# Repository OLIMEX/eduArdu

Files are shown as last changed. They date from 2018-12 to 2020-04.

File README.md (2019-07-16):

# eduArdu
Open Source Hardware Educational board based on Arduino Leonardo

Product page: https://www.olimex.com/Products/Duino/AVR/eduArdu/open-source-hardware

Introduction video: https://youtu.be/3kFrveMF56s

# Getting started

## Arduino IDE

* [Download and install Arduino IDE](https://www.arduino.cc/en/Main/Software)
* Open Arduino IDE
* Click **Sketch > Include Library > Add .ZIP library...** and add all libraries provided with this repository
* Open a sketch, compile and upload it to Olimex eduArdu

## Licensee
* Hardware is released under Apache 2.0 Licensee
* Software is released under GPL3 Licensee
* Documentation is released under CC BY-SA 3.0

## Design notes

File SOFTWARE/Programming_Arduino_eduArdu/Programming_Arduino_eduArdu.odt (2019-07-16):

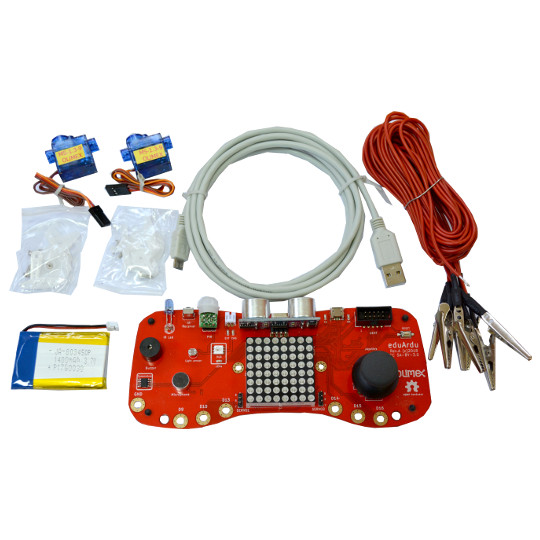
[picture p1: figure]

Програмиране с Arduino и eduArdu

July 2019

# 1. Инсталиране на Arduino IDE

1.1 Използвайте линка за сваляне на Arduino IDE в зависимост от операционната система :

https://www.arduino.cc/en/Main/Software

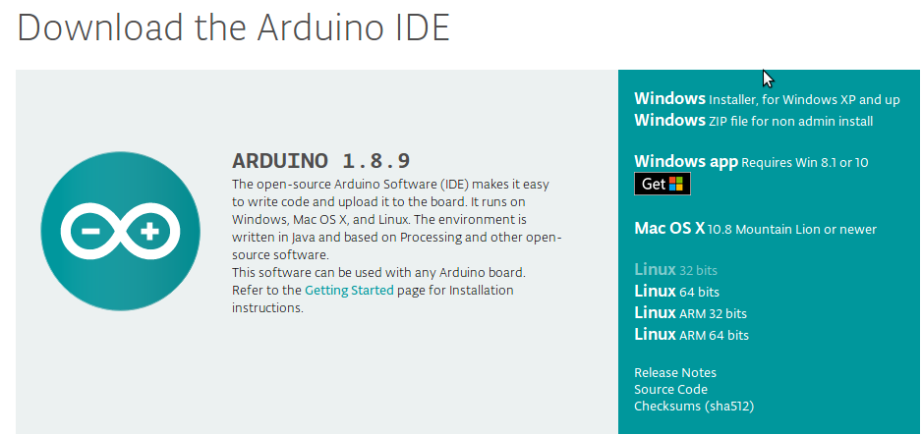
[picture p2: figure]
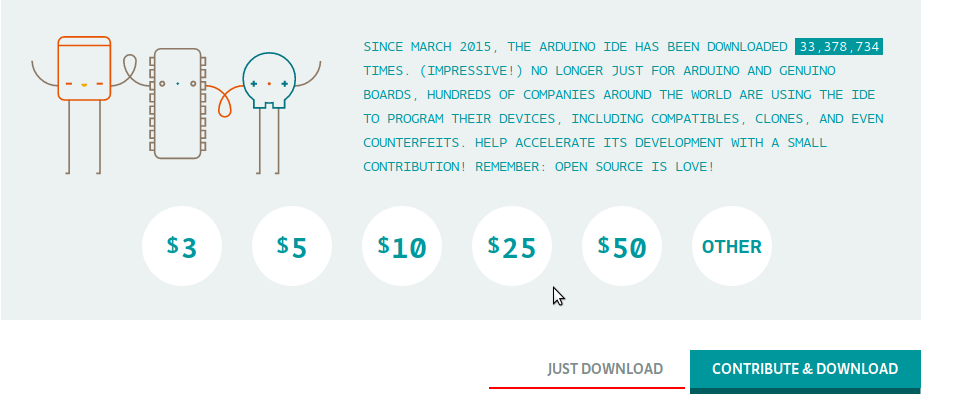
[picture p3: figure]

2.1 Инсталирайте Arduino IDE

3.1 Използвайте линка за да свалите всички примери и библиотеки необходими за eduArdu чрез натискането на подчертания бутон :

https://github.com/OLIMEX/eduArdu

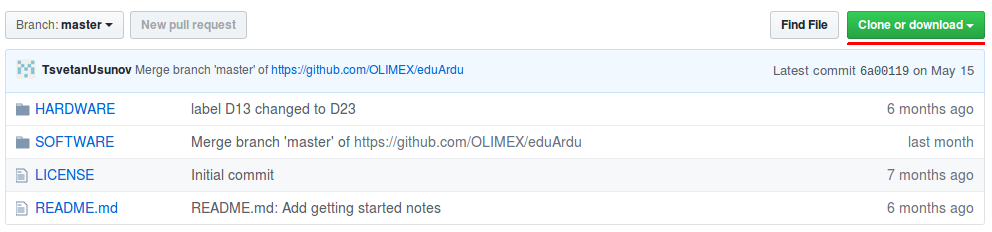
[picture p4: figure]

4.1 Стартирайте Arduino IDE. Влезте в Sketch-include Library-Add .ZIP Library

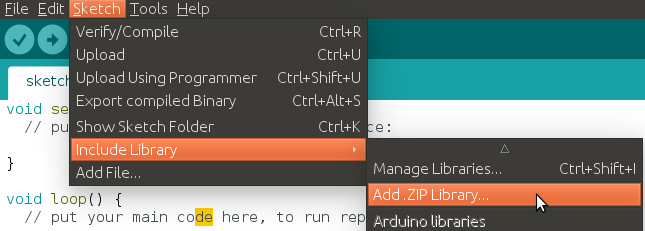
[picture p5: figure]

5.1 Изберете папката в която сте запазили сваленото от точка ( 3. ) и започнете едно след друго да добавяте библиотеките, като следвате стъпки 4 и 5 . Файловете, който трябва да добавите ще се намират под Files а папката в която сте запализи файла от точка 3 ще се намира под Folders.

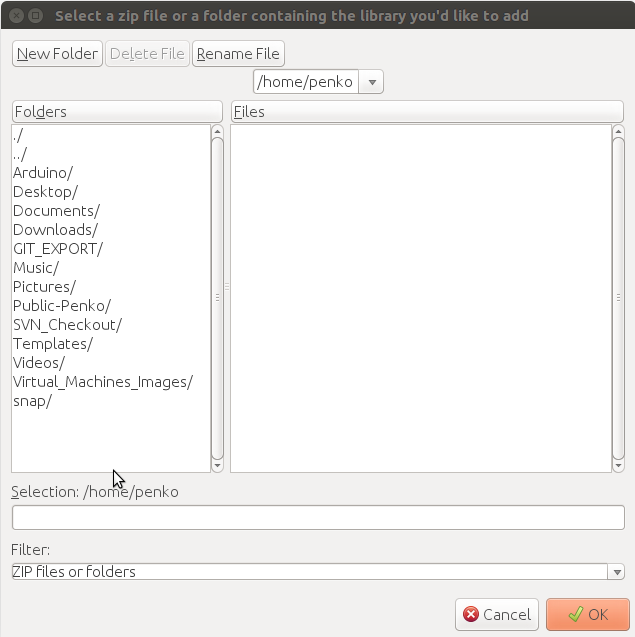
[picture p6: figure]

За eduArdu :

Платката EduArdu е предназначена за обучение. Тя е снабдена с множество сензори като например:

-осветление

-инфрачервен диод

-инфрачервен приемник

-сензор за движение

-сензор за температура

Платката разполага още и с:

-LED матрица

-микрофон

-трицветен светодиод

-два Servo входа

-джойстик

-UEXT вход

-Buzzer

# 2. Инсталиране на Olimex board support

Влизате в file-preference.

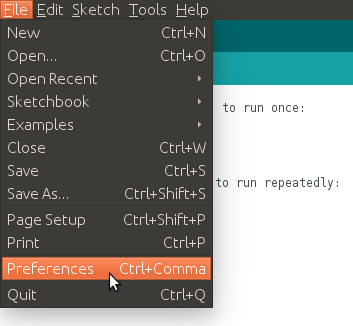
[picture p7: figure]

Копирате линка:

h (https://raw.githubusercontent.com/OLIMEX/Arduino_configurations/master/AVR/package_olimex_avr_index.json)ttps://raw.githubusercontent.com/OLIMEX/Arduino_configurations/master/AVR/package_olimex_avr_index.json

След това го поставяте в Additional board manager URLs:

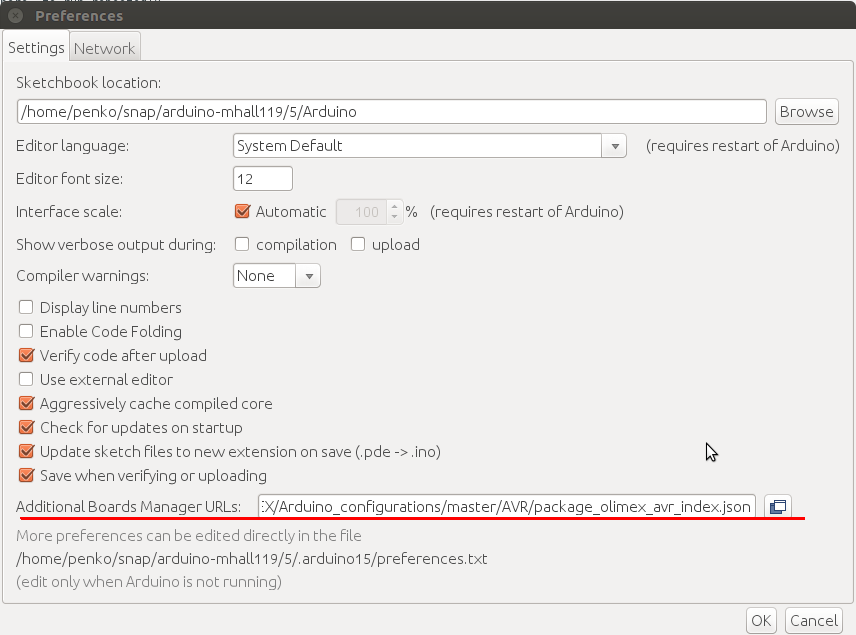
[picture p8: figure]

Влезте в tools-board-boards manager : и инсталирайте Olimex AVR boards.

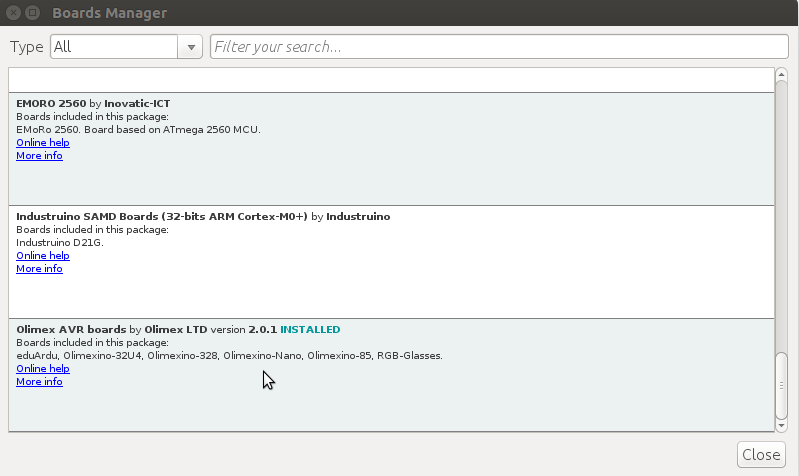
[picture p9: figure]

# 3. Как да конфигурираме Arduino IDE

Първо: Свържете платката с USB към компютър. Втора стъпка:конфигурирайте платката като за целта трябва да влезнете в Tools-Board и изберете eduArdu. След това Port и изберете вашата платка.

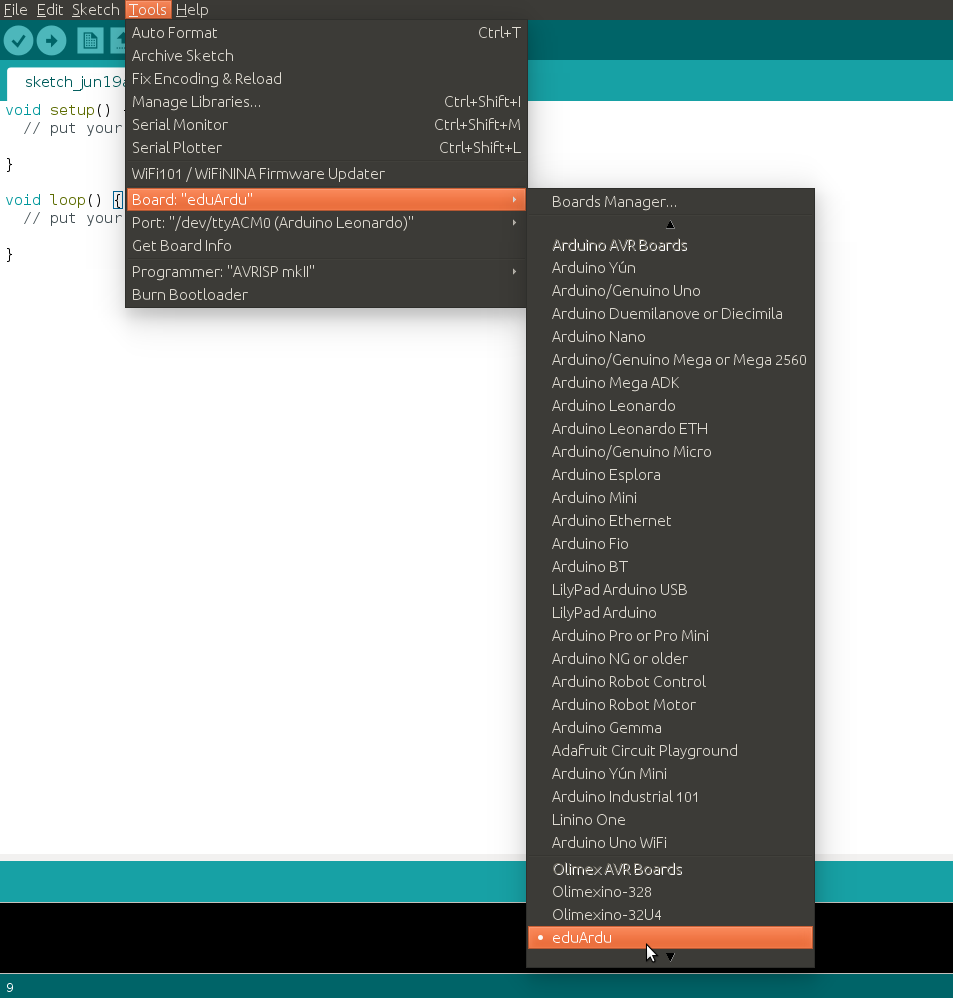
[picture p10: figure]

# 4. LED Matrix

#include <string.h>

#include "LED_Matrix.h" // Използваме LED_Matrix.h за да имаме достъп до SlideRight() // и SlideLeft().

#include "font.h" // Чрез font.h инициализираме азбуката и всички знаци.

#include "Joystick.h" // Инициализира джойстика.

#define JOYSTICK_X A0 // Където срещне OYSTICK_X го заменя с аналогов вход A0.

#define JOYSTICK_Y A1 // Където срещне OYSTICK_Y го заменя с аналогов вход A1.

#define JOYSTICK_BUTTON 31 // Където срещне JOYSTICK_BUTTON го заменя с 31

#define SPEED 110 // Където срещне SPEED го заменя с 110

#define LED_LATCH 11 // Инициализираме LED матрицата.

#define LED_DATA 16

#define LED_CLOCK 15

LED_Matrix Matrix(LED_LATCH,LED_DATA,LED_CLOCK); // Задаваме стойност на функция Matrix // която приема като параметри LED // Matrix pin.

Joystick Joy(JOYSTICK_X, JOYSTICK_Y); // Използваме функцията за да взимаме // стойностите на Х(лява/дясна граница) и на // Y(горна/долна граница) на джойстика.

unsigned char Text[STRING_MAX_CHAR] = "Olimex eduArdu LED matrix example!";

/*

Използва се за изписването на текста върху LED matrix.Пример ако искаме да изпишем

“Hello Olimex” трябва да го променим така :

unsigned char Text[STRING_MAX_CHAR] = "Hello Olimex";

*/

char Terminal_Output[256]; // Използва се за изписване на резултатът в конзолата // като дължината на символите зависи от цифрата // която е в скобите “[ ]”.

void setup()

{

Serial.begin (115200); // Използва се за инициализиране.Т.е скоростта на // трансфера на данните.

Matrix.DisplayText (Text, 0); // Използва се за инициализиране на текста като // втория параметър е за да може текста да започне
} // отначало.

static unsigned long Time=0, PrevTime=0; // Задаваме стойности за променливи Time,PrevTim.

Time = millis(); // Записваме в Time, изтеклото време в милисекунди от // пускането на платката.

if (Time-PrevTime > 110) // Изважда от Time променливата PrevTime и провер
{ // дали е по малко от 110.

PrevTime = Time; // PrevTime взема стойността на Time.

if (Joy.X () < 20) // Проверява дали джойстика е натиснат наляво.

Matrix.SlideLeft (1); // Ако е натиснат наляво. Функцията премества текста // наляво.

if (Joy.X () > 80) // Проверява дали джойстика е натиснат надясно.

Matrix.SlideRight (1); // Ако е натиснат надясно.Функцията премества текста // надясно.

if (Joy.Y () < 20) // Проверява дали джойстика е натиснат надолу. Ако е // натиснат преминава на другия ред и извиква // функцията която намалява светлината.
Matrix.ChangeBrightness (-10);

if (Joy.Y () > 80) // Проверява дали джойстика е натиснат нагоре. Ако е // натиснат преминава на другия ред и извиква // функцията която увеличава светлината.

Matrix.ChangeBrightness (10);

Serial.println ("--------------------------------"); // Изписва на конзолава намиращите

// се символи между кавичките в // скобите.

sprintf (Terminal_Output, "Joystick: X = %d%%; Y = %d%%; Button: %d", (int)Joy.X(), (int)Joy.Y(), Joy.But()); // Взима стойностите X,Y,Button и ги записва в // Terminal_Output

Serial.println (Terminal_Output); //Изписва съдържанието на Terminal_Output.

}

Matrix.UpdateText (); //Актуализира матрицата.

}

# 5. Масиви

Това са последователни клетки от паметта в който можем да запазваме различни данни от различен тип. Пример за това е в проекта Led Matrix,използването на :

unsigned char Text[STRING_MAX_CHAR] = "Olimex eduArdu LED matrix example!";

char Terminal_Output[256];

При тези масиви искаме да запишем думи. Пример ако искаме да сменим текста който се изписва на матрицата ще променим текста в кавичките :

unsigned char Text[STRING_MAX_CHAR] = "Hello Olimex";

така текста на матрицата ще се промени.

# 6. Функции и Проверки

Тук ще разгледаме някой от функциите и проверките в примера за Led Matrix.

## 6.1 Функции

void setup()

{

Serial.begin (115200);

Matrix.DisplayText (Text, 0);

}

За пример можем да вземем Void Setup() тази функция не връща като резултат нищо.Използва се за инициализиране на входове/изходи. В тялото(т.е. намиращото се в { } ) на тази функция имаме Serial.begin (115200); което инициализира скоростта на трансфер на данните.

Функцията Matrix.DisplayText (Text, 0); изписва на екрана записания текст в масива Text и откъде да започне текста като ако применим втория параметър (Text, 0) да не е 0 ще видим че текста се измества.

## 6.2 Проверки

Нека разгледаме

if (Time-PrevTime > SPEED)

{

PrevTime = Time;

if (Joy.X () < 20)

Matrix.SlideLeft (1);

if (Joy.X () > 80)

Matrix.SlideRight (1);

if (Joy.Y () < 20)

Matrix.ChangeBrightness (-10);

if (Joy.Y () > 80)

Matrix.ChangeBrightness (10);

}

Тук имаме проверки “ if () ” при нея можем да сложим условие в ( ), проверяваме,ако условието е изпълнено(вярно е) програмата преминава на следващия ред и го изпълнява.При първият if (Time-PrevTime > SPEED) проверяваме Time-PrevTime дали е по-голямо от SPEED където SPEED e зададено като статична стойност чрез #define SPEED 110 намиращо се в началото на програмата.Пример за променянето на SPEED e :

#define SPEED 40

така след промяната на текста чрез натискане на джойстика,той ще се движи по-бързо.

Когато програмата навлезе в тялото на функцията :

{

PrevTime = Time;

if (Joy.X () < 20)

Matrix.SlideLeft (1);

if (Joy.X () > 80)

Matrix.SlideRight (1);

if (Joy.Y () < 20)

Matrix.ChangeBrightness (-10);

if (Joy.Y () > 80)

Matrix.ChangeBrightness (10);

}

Тук отново имаме проверки от тип if ( ) при тях обаче проверяваме дали сме натиснали джойстика if (Joy.X () < 20) наляво ако условието в скобите ( ) е изпълнено, т.е. джойстика е натиснат,наляво програмата изпълнява Matrix.SlideLeft (1); .При изпълнението на тази функция можем да променим стойността с която текста преминава през матрицата :

Matrix.SlideLeft (3) стойността може да е произволна.

Същото при Matrix.ChangeBrightness (-10); може да променяме колко да се увеличава осветителността.

# 7. Цикли

Тук ще се запознаем с основните цикли. For () , While() ,do While.

## 7.1 Цикъл For ( )

for(int i=0; i<50; i++)

{

//тяло на цикъла

}

В този пример операндите, който приема цикъла са нулиране на применливата “i” int i=0,

приверка дали “i” е по-малко от 50 и увеличаване на “i” с едно. Програмата преминава през цикъла по следния начин :

1. Нулирането на “i” (int i=0)

2.Проверка дали “i” е по-малко от 50

3.Навлизане и изпълнение на тялото на цикъла

4.Увеличаване на “i” с едно

Пример за такъв цикъл ще дадем от програмата с използване на микрофона:

for(int i=0; i<50; i++)

{

int Sample;

Sample = analogRead(MICROPHONE);

if (Sample > Max)

Max = Sample;

if (Sample < Min)

Min = Sample;

if((Max-Min) > THRESHOLD)

{

digitalWrite (LED, !digitalRead(LED));

delay(100);

break;

}

}

За тялото на функцията и проверките в него, може да прочетете в глава 6.

## 7.2 Цикъл While ( )

Тук цикъла има само един параметър и това е условието :

While (“условие”)

{

//тяло на цикъла

}

При този цикъл докато условието е вярно ще се повтаря кода в тялото.

## 7.3 Цикъл do While ( )

Тук цикъла има пак един параметър и това е условието но тук тялото се изпълнява и след това се прави проверката :

do

{

//тяло на цикъла

}While (“условие”)

!! Внимание цикъла може да се изпълни поне един път.

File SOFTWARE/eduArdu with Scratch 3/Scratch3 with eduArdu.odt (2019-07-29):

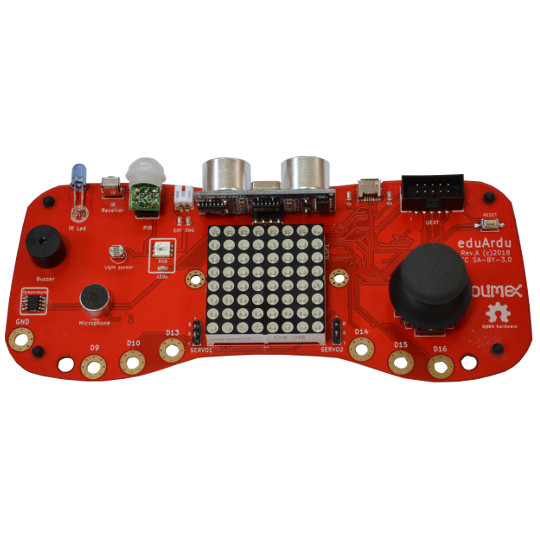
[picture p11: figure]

First steps with

Scratch 3 and eduArdu

Rev.1 July 2019

olimex.com

# Step 1 prepare eduArdu

What you need is eduArdu (https://www.olimex.com/Products/Duino/AVR/eduArdu/open-source-hardware) or (https://www.olimex.com/Products/Duino/AVR/eduArdu/open-source-hardware)eduArdu-QS (https://www.olimex.com/Products/Duino/AVR/eduArdu/open-source-hardware) Open Source Hardware board from Olimex.

Then you need to program it with example #20 from GitHub (https://github.com/OLIMEX/eduArdu/tree/master/SOFTWARE)

20_eduArdu_Makey-Makey

The code program eduArdu when sense touch to D9-D16 to send these keys:

D9 - „a“

D10 - „s“

D13 - „d“

D14 - „f“

D15 - „g“

D16 - „w“

Joystick Up – Key-Up

Joystick Down – Key-Down

Joystick Left – Key-Left

Joystick Right– Key-Right

Joystick Button – Space

Note that you can re-define any of these in the code if you need!

# Step 2 configure Scratch3

Go to Scratch 3 web site:

https://scratch.mit.edu/

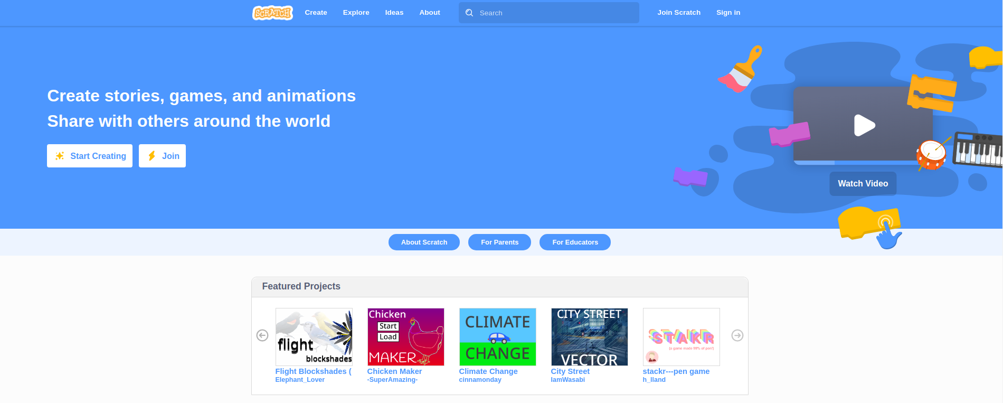
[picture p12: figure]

Click on „Start Creating“, you will see project page:

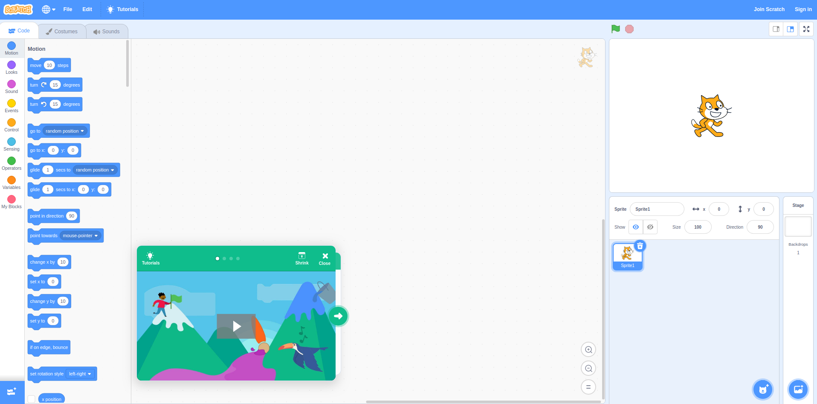
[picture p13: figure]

Click on Down Left corner „Add-Extension“ icon:

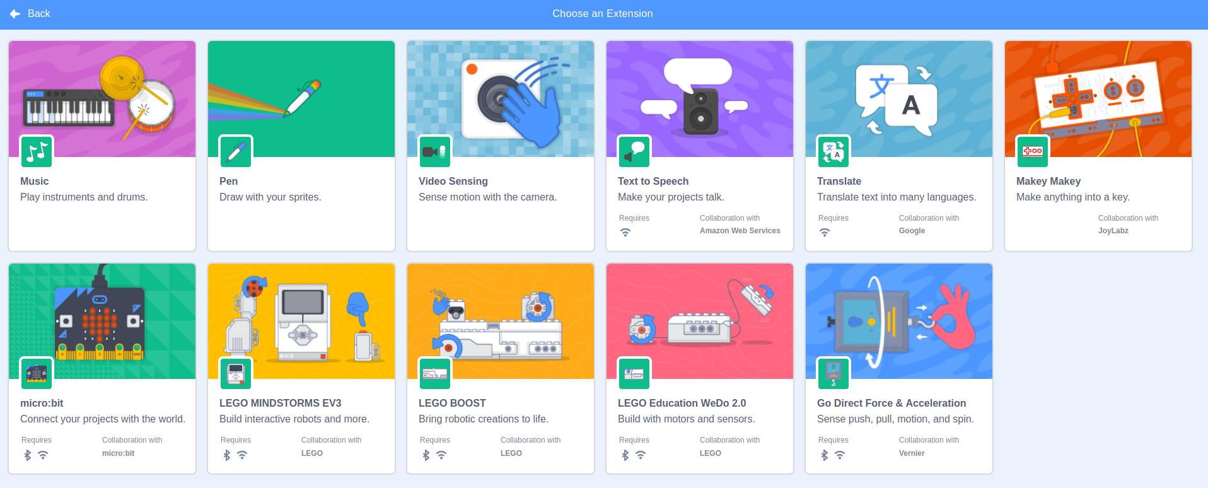
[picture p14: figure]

Select Makey Makey , when yo ugo bsck you will see new MakeyMakey blocks:

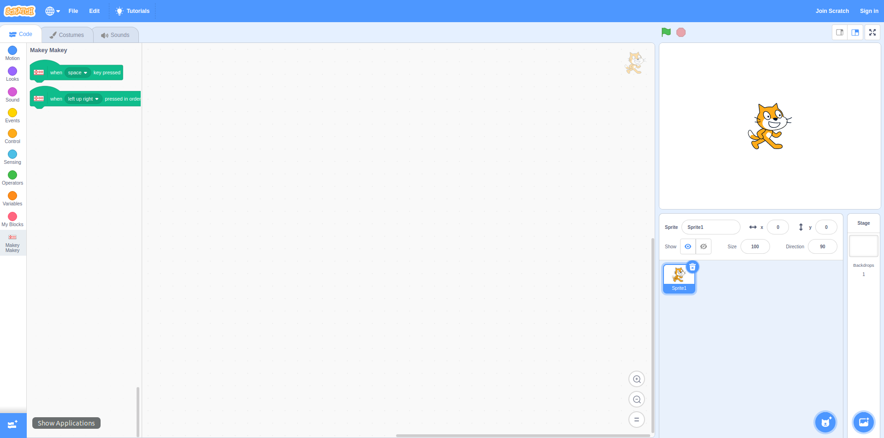
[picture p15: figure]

# Step 3 write your own program

Now you can make your program using MakeyMakey blocks.

The program below does this: when D9 is touched the Cat will say „Hello“, when D10 is touched the Cat say „Hmm“, when D13 is tpoouched Meow sound is payed.

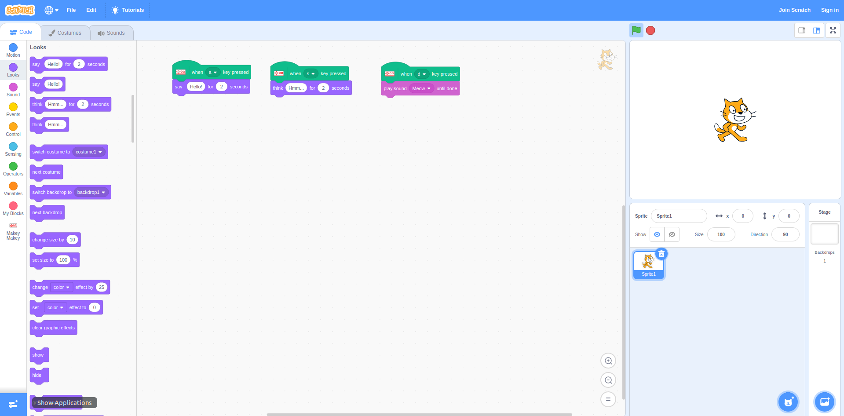
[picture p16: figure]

Here you can see this in action: https://youtu.be/GwdAzChfQ9Y

Have fun!!

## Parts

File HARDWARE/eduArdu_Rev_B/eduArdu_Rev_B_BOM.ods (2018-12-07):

Designation | Quantity | Designator | Package
СВЕТОДИОД МАТРИЦА 8x8 GYXM-1588ASRD | 1 | U9 | GYX1588AB
SMD КОНД 0805 47 UF 6.3V 20% | 7 | C11, C12, C17, C18, C24, C25, C26 | C_0805_5MIL_DWS
SMD КОНД 0603 1 UF 10V X5R | 6 | C1,C6,C13,C16,C22,C23 | C_0603_5MIL_DWS
SMD РЕЗ 0402 10 M 5% | 6 | R26, R27, R28, R29, R30, R31 | R_0402_5MIL_DWS
СЪЕДИНИТЕЛ DW02R | 1 | BAT_CON1 | LIPO_BAT-CON2DW02R
PIR-SB312 | 1 | PIR1 | HN1x3
ИС VS1838B | 1 | U3 | RPM7236-H8-V
SMD СЪЕДИНИТЕЛ B-V-10-LF (GBH254SMT-10) | 1 | UEXT1 | UEXTM-SMD
SMD ИС LM358DR SOIC8 | 1 | U10 | SO-8
SMD РЕЗ 0402 10 K 5% | 10 | R2, R3, R8, R10, R11, R18, R20, R21, R22, R25 | R_0402_5MIL_DWS
SMD РЕЗ 0402 20 K 5% | 1 | R24 | R_0402_5MIL_DWS
SMD РЕЗ 0402 100 OHM 1% | 3 | R14,R17,R19 | R_0402_5MIL_DWS
SMD РЕЗ 0402 100 K 5% | 1 | R16 | R_0402_5MIL_DWS
SMD РЕЗ 0402 1 K 5% | 1 | R15 | R_0402_5MIL_DWS
SNS-LDR5MM | 1 | R7 | R_PHOTO
SMD СЪЕДИНИТЕЛ MISB-SWMM-5B-LF | 1 | USB1 | USB-MICRO_MISB-SWMM-5B_LF
SMD ИС AP1231-3.3V (SOT23-5) | 1 | VR1 | SOT-23-5
SMD ИС TCN75AVOA713 | 1 | U4 | SO-8
BL4054B-42TPRN(SOT23-5) | 1 | U1 | SOT-23-5
SMD РЕЗ 0402 2 K 5% | 4 | R1,R4,R9,R23 | R_0402_5MIL_DWS
SMD РЕЗ 1206 6.8 OHM 5% | 1 | R13 | R_1206_5MIL_DWS
SMD РЕЗ 0402 22 OHM 5% | 3 | R5,R6,R12 | R_0402_5MIL_DWS
SMD СВЕТОДИОД 0603 ЖЪЛТ 300 mCd | 3 | LED1,LED4,LED6 | LED_0603_KA
WS2812S | 1 | LED5 | WS2812_NO_SILK
SMD СВЕТОДИОД 0603 ЗЕЛЕН 300 mCd | 2 | LED2,LED3 | LED_0603_KA
IRML6402 | 1 | FET1 | SOT23
SMD ДИОД 1N5819 (SS14) SMA | 1 | D1 | SMA-KA
SMD КОНД 0402 47 PF C0G 5% 50VDC | 1 | C21 | C_0402_5MIL_DWS
SMD КОНД 0402 100 NF 10% 10VDC | 8 | C5, C8, C9, C10, C14, C15, C19, C20 | C_0402_5MIL_DWS
SMD КОНД 0603 2.2 UF X5R 6.3VDC 10% | 2 | C2,C7 | C_0603_5MIL_DWS
SMD КОНД 0402 20 PF NP0 50VDC | 2 | C3,C4 | C_0402_5MIL_DWS
RA1206_(4x0603)_4B8_22R | 2 | RM1,RM2 | RA1206_(4X0603)_4B8_mine
SMD ИС ULN2003AD | 2 | U7,U8 | SO-16
SMD ИС 74HC595D | 2 | U5,U6 | SO-16
SNS-HCSR04 | 1 | USON1 | USONIC-PING
HN1x3 | 2 | SERVO1,SERVO2 | HN1x3
T1107A(6x3,8x2,5MM) | 1 | SW1 | T1107A(6x3,8x2,5MM)
ATmega32U4-AU | 1 | U2 | TQFP44
16.000MHz/SMD5x3.2/12pF | 1 | Q1 | HCX-4S_2Pins_5.0x3.2mm
МИКРОФОН AMF-O97A44-NBAB C.MIC | 1 | MK1 | MIC
IR333 | 1 | LED7 | LED-5mm-PTH-AK
JOYSTICK 10K-CAP | 1 | JS1 | JOYSTICK
BUZZER 1221P | 1 | BUZ1 | BUZZER
RUBBER-FEETS-B | 4

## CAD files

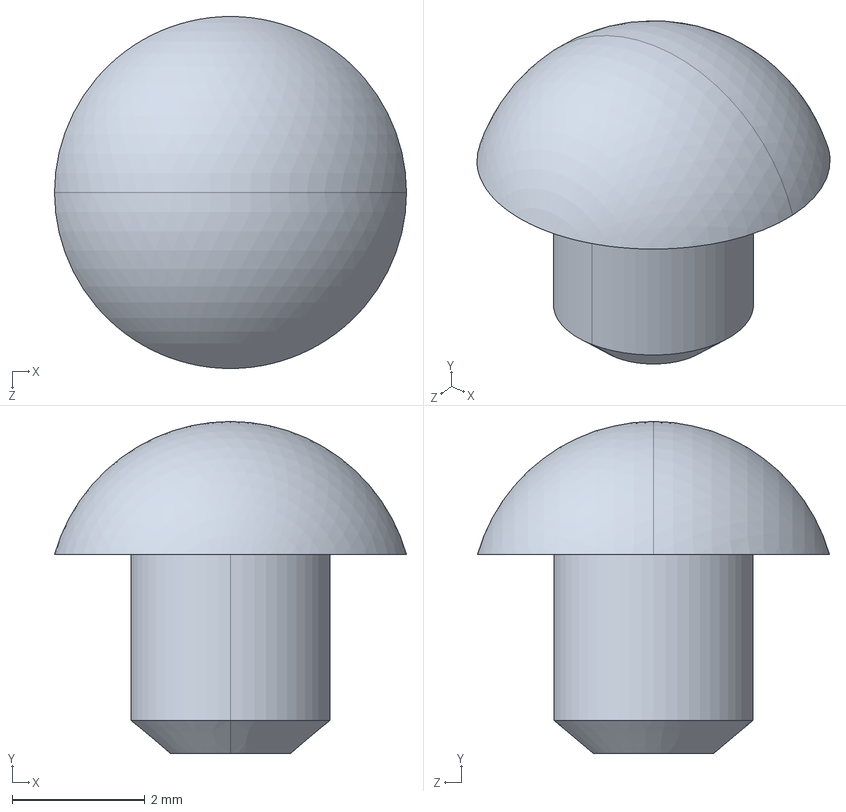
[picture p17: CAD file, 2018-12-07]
HARDWARE/eduArdu_Rev_B/3d/3dusers/rubber_feet.step
5.30 x 5.00 x 5.30 mm

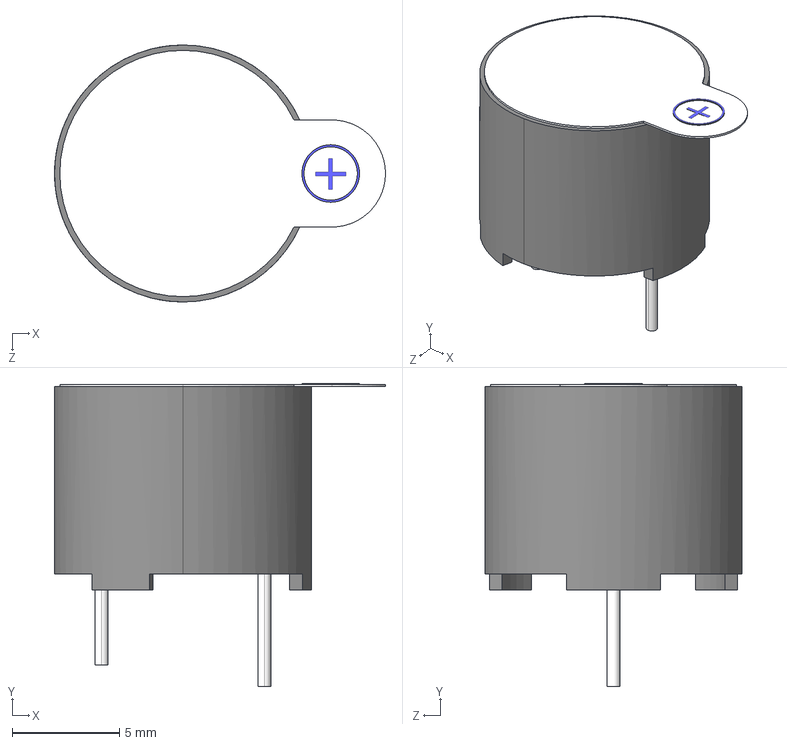
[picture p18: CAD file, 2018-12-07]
HARDWARE/eduArdu_Rev_B/3d/3dusers/ALSRobot-BUZZER.step
15.5 x 14.2 x 12.0 mm

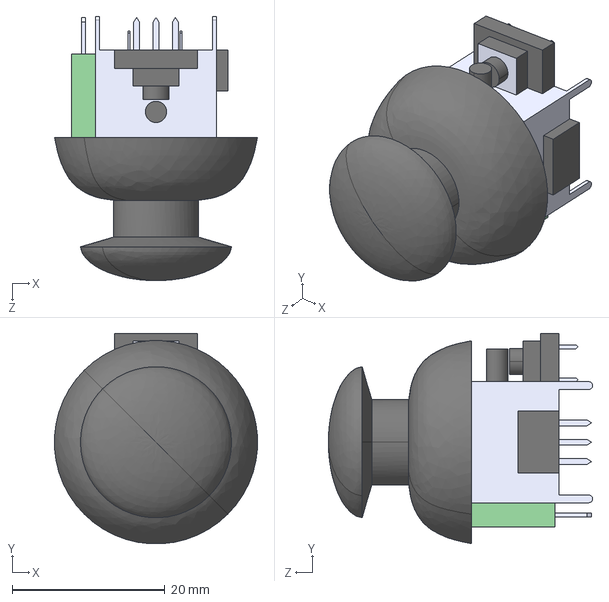
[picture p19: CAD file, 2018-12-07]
HARDWARE/eduArdu_Rev_B/3d/3dusers/JS-PS2.step
26.6 x 27.6 x 34.7 mm

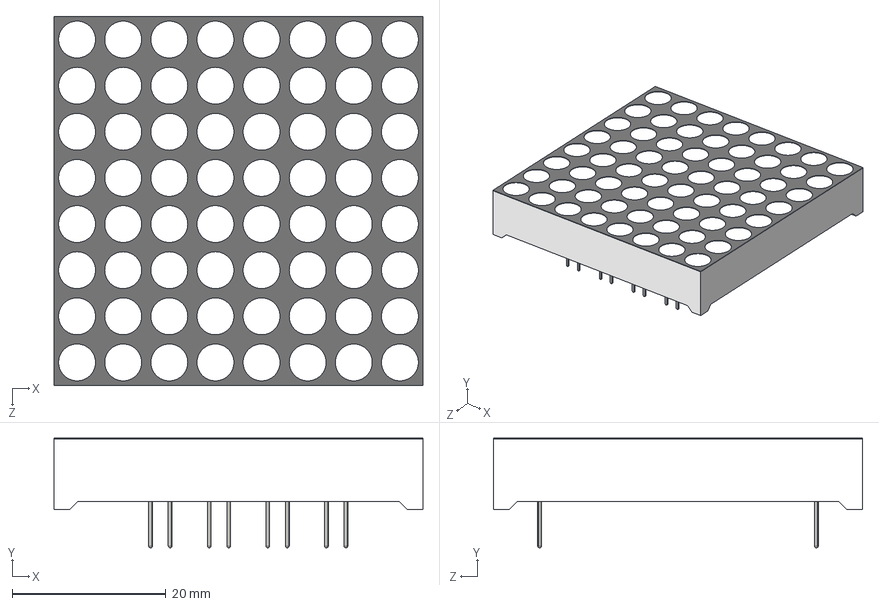
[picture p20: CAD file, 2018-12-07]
HARDWARE/eduArdu_Rev_B/3d/3dusers/User_Library-LED_Matrix.STEP
48.0 x 14.3 x 48.0 mm
User Library-LED Matrix_TOM-1988AsW-B
User Library-LED Matrix_Pin x 16
User Library-LED Matrix_top

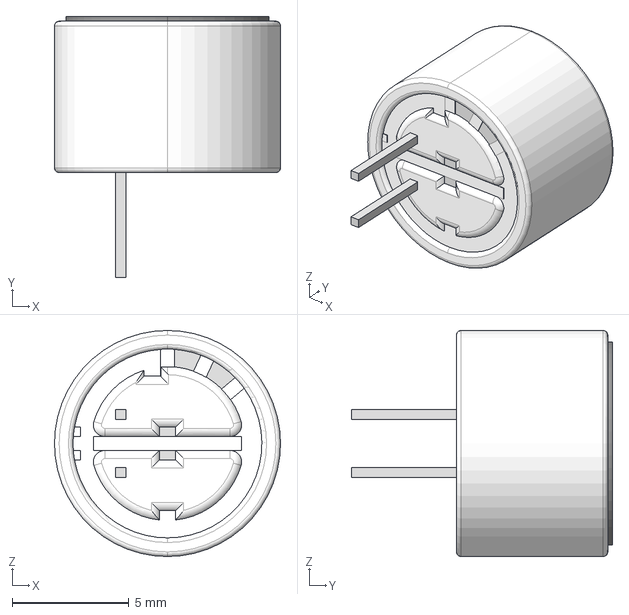
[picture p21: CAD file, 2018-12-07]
HARDWARE/eduArdu_Rev_B/3d/3dusers/cma-6542pf.stp
9.70 x 11.2 x 9.70 mm

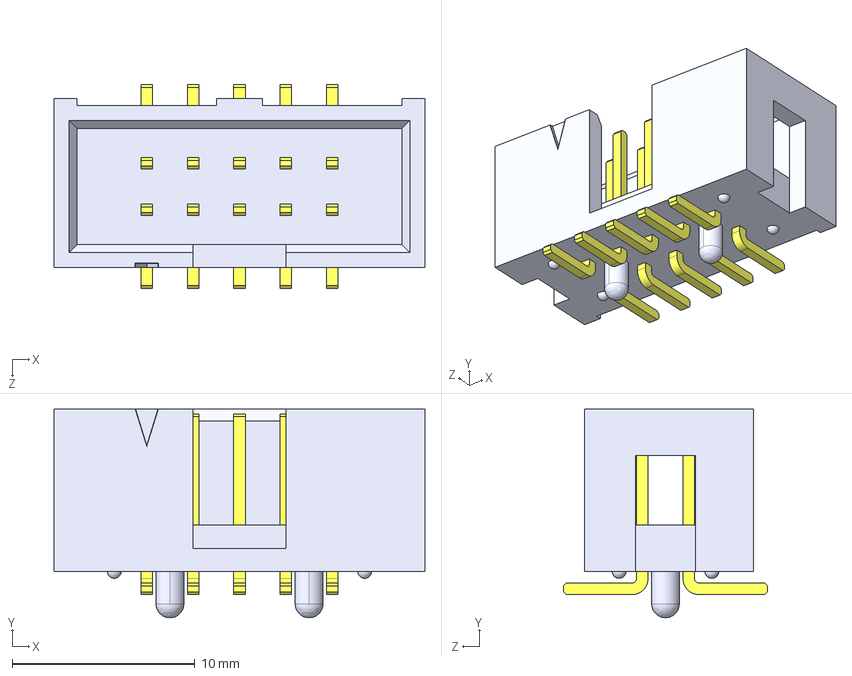
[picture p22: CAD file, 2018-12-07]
HARDWARE/eduArdu_Rev_B/3d/3dusers/UEXT-SMD.STEP
20.3 x 11.4 x 11.2 mm
User Library-HTST-105-01-F-DV-A__HTST-105-01-DV-A_header
User Library-HTST-105-01-F-DV-A__HTST-First_Position_Indicator
User Library-HTST-105-01-F-DV-A__T-1S6-05-01-DV_

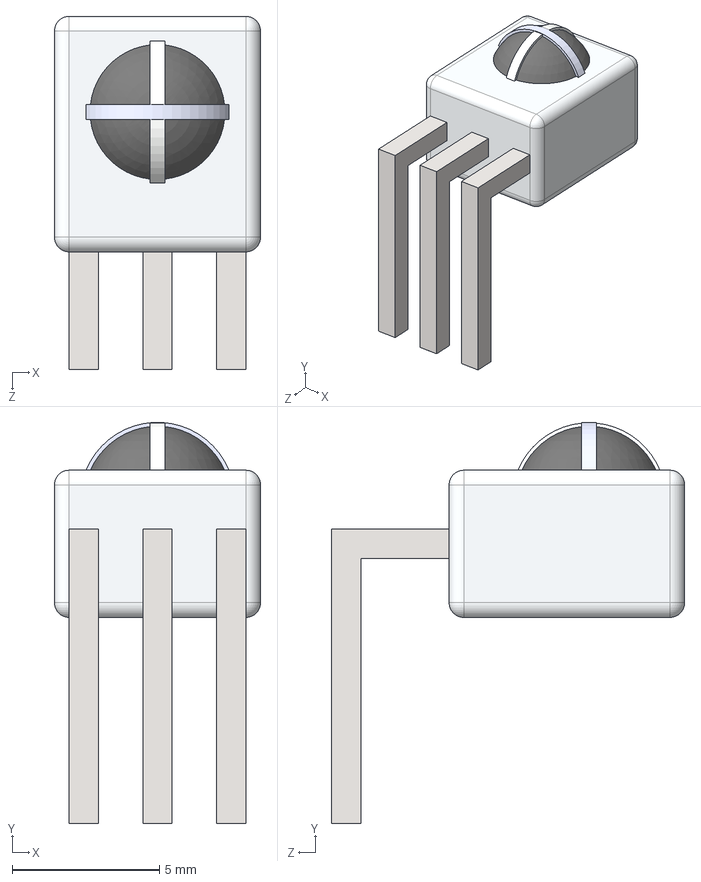
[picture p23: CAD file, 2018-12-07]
HARDWARE/eduArdu_Rev_B/3d/3dusers/User_Library-Parallax-IR.step
7.00 x 13.6 x 12.0 mm

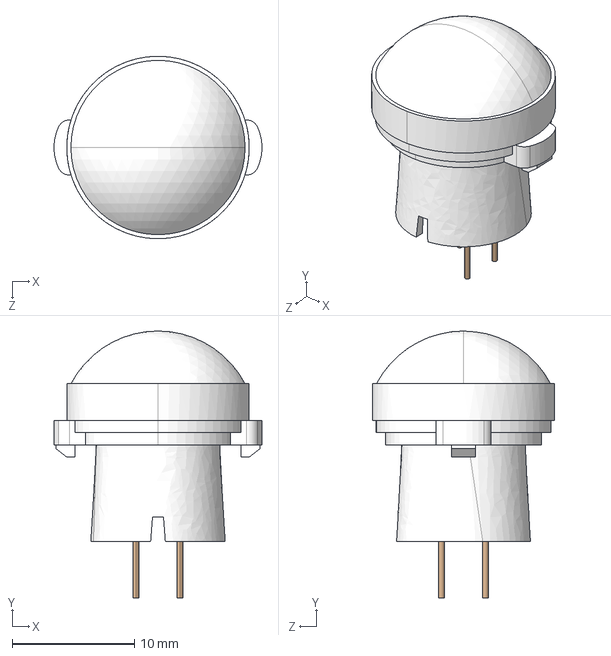
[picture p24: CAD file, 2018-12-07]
HARDWARE/eduArdu_Rev_B/3d/3dusers/User_Library-EKMB1393111K.step
17.0 x 21.8 x 14.9 mm

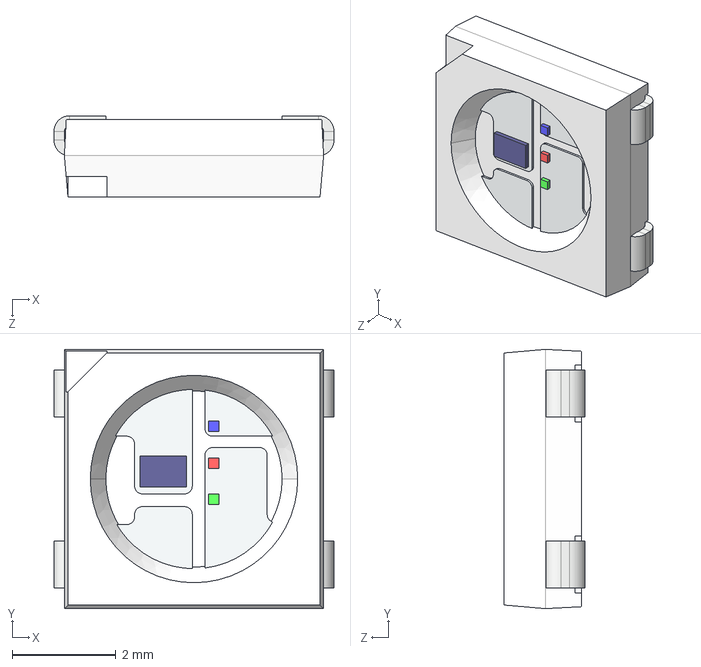
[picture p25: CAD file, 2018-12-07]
HARDWARE/eduArdu_Rev_B/3d/3dusers/User_Library-ws2812B-1.step
5.40 x 5.00 x 1.57 mm

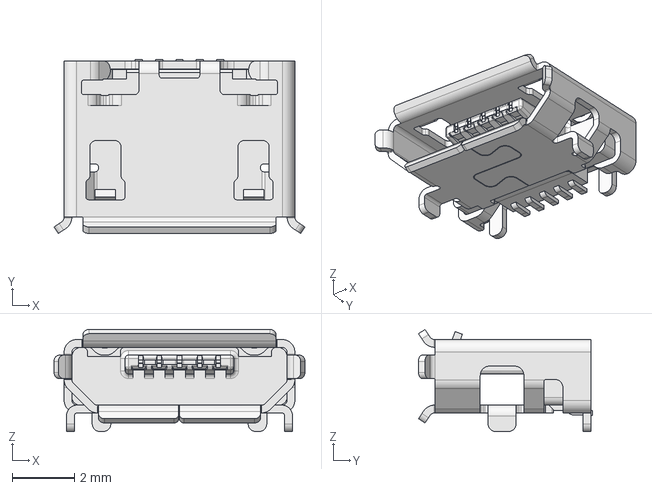
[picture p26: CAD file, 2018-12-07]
HARDWARE/eduArdu_Rev_B/3d/3dusers/10118194.step
8.05 x 5.58 x 3.27 mm

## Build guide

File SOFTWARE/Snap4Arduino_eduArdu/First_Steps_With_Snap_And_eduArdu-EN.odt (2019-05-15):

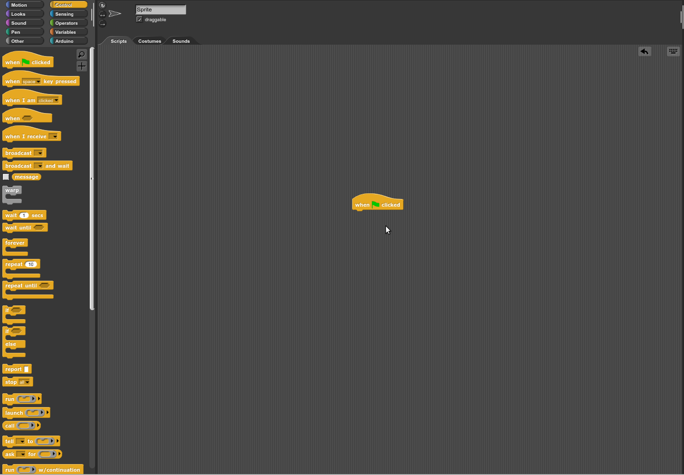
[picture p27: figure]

First steps with "Snap4Arduino"

Create your "Snap" for eduArdu

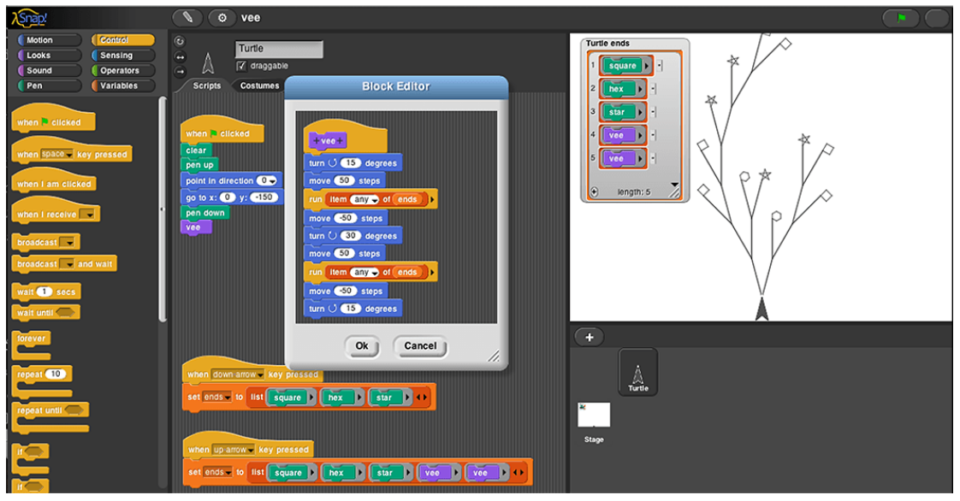
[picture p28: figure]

release 1.0/20.12.2018

Copyright© 2018, OLIMEX Ltd

Released under CC-SA-BY-3.0 (https://creativecommons.org/licenses/by-sa/3.0/)

I. Part - Preparations:

1. What is "Snap4Arduino" ?

- This is modified version of Snap! (https://snap.berkeley.edu/) - visual programming language, which allows communication with almost all Arduino based boards.

- Interractive software, which beginners in programming and Arduino can use to create their first program without knowledge for particular programming language. By using small blocks the programming with Snap4Arduino is like to solve puzzle.

2. What do we need to work with Snap4Arduino ?

- Instlled ArduinoIDE

- Installed Snap4Arduino

- Copy of eduArdu Github repository (not obligatory)

2.1 Installing ArduinoIDE

- Download ArduinoIDE from:

https://www.arduino.cc/en/Main/Software

- Choose the right installer according your OS.

- Install Arduino IDE.

2.2 Installing Snap4Arduino

- Go to http://snap4arduino.rocks/

- From the menu bar click on "Download" button

- Choose the right insttaller for your OS.

- Launch Snap4Arduino installer or extract Snap4Arduino archive.

2.3. Cloning eduArdu Github repository

- Go to https://github.com/OLIMEX/eduArdu

- Clone the repository via GIT or click on

"Clone or download" -> Download ZIP

2.4. How to load eduArdu Firmata?

- Go to your local copy of the already cloned repository or extract already downloaded ZIP file. Then go to the directory:

/SOFTWARE/Snap4Arduino_eduArdu/eduArdu_Firmata/

- Open with ArduinoIDE the sketch file "eduArdu_Firmata.ino".

- Load all libraries sfrom /SOFTWARE/libraries/

To do so, click on the "Sketch" menu; after that go to "Include Library" sub-menu; choose "Add .ZIP library"

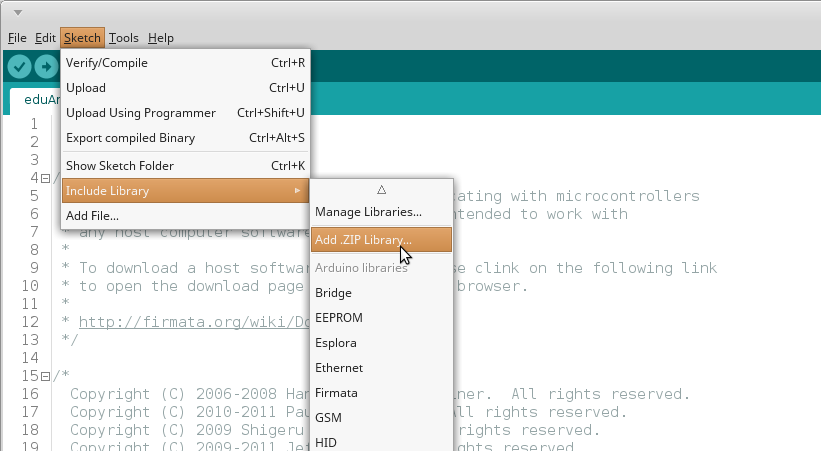
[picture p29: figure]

In the dialogue window point the full path to the library you want to include. This step is repeated for every library in "/libraries/"

2.5. After loading all the libraries:

Once included there is no need to include again the same library.

II. Part - Intro to Snap4Arduino

Launch Snap4Arduino application.

You should see interface like this:

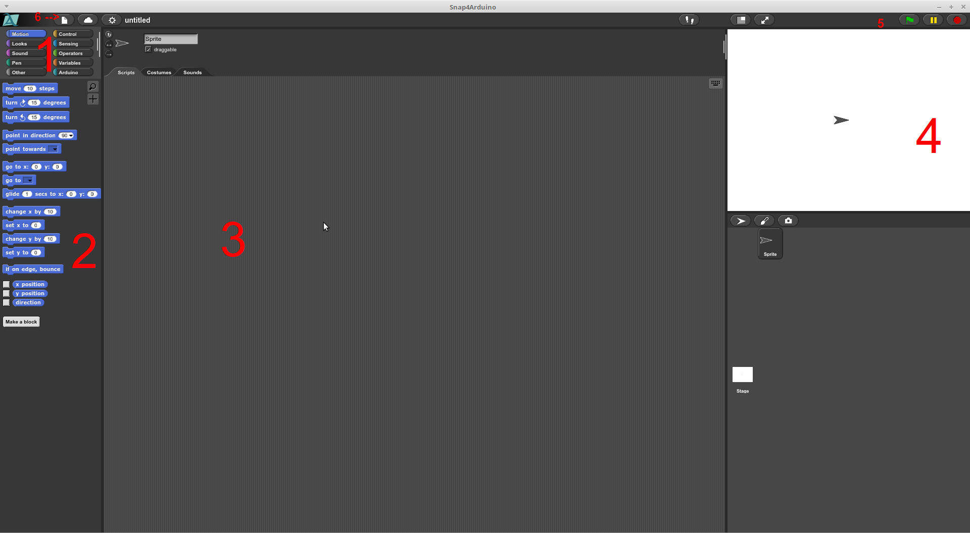
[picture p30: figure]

Short review of interface regions:

1. Block categories. Every category contains similar block types. Block categories are grouped according the block's functionality. There are several categories:

- Motion - Blocks used to moove Sprites

- Looks - pop-up balloons with information/text

- Sound - contains blocks for sound playback from PC

- Pen - Controls the pen (look label 4).

- Control - functions for start/stop, delay, if/else conditions, loops and etc. With those blocks you shall start and stop your program.

- Operators - Contains different operators for arythmetic calculations. Also this category contains blocks which can execute JavaScript code.

- Variables - Blocks for creation and controling variables.

- Arduino - This category contain all block which are related to Arduino. You can control motors, sensors; read/write data and etc.

- Other - This category is empty by default, but we can use it in future for our own purposes.

2. Block types.

There are 3 block types.

Command simply takes an action and continues execution of the program .

Reporter similar with Command blocks. These blocks also return results, which can be used as input to other blocks. Can not be used alone, they should always be put into body of another block.

Predicate very similar to Reporter blocks. These blocks return only True/False results.

Blocks can be used standalone. If you drag a block and leave it in Pane 3, you can activate the block by clicking on it. You can also connect different blocks, arranging them one under another, making application.

Command can be put between other blocks.

Every block or array of block can be replicated. That means, there's no need to make every time same block combination, as we can simply replicate an existing one.

Complex blocks or those created by us can be edited. Simply click with the right button on the block and choose the menu "edit":

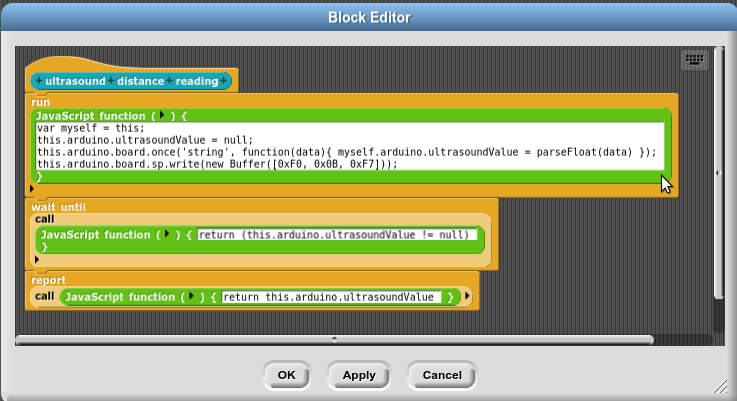
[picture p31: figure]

3. Code pane - We drop the blocks that will be used in that pane. Most dialogue windowses would appear in that pane.

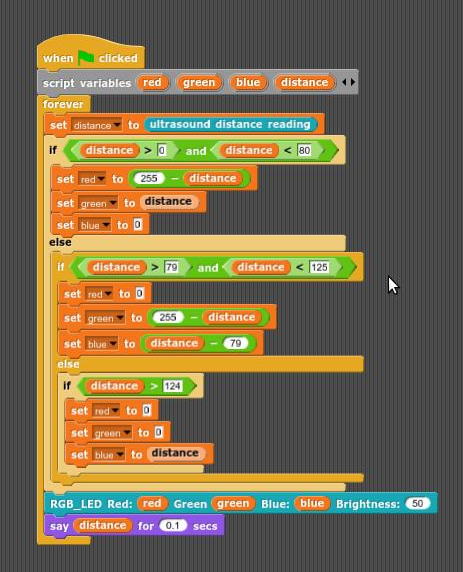
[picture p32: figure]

4. Screen - used for drawing and displaying our Sprites and animations. Block types like "Motion", "Looks", "Sensing", "Pen" woul moove the cursor on that pane; create images and animations; moove sprites.

5. Menu

File; Cloud; Settings.

- From File menu, we open saved projects; create new project; import library and etc.

- Cloud menu allows us to connect to Snap4Arduino cloud and store or load our projects.

- Settings menu - contains different interface settings

Part III - "Hello World"

1. Connect MicroUSB cable to your eduArdu board.

2. Launch Snap4Arduino application

3. Go to Arduino category

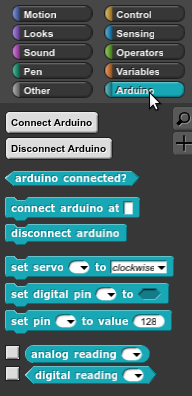
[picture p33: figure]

If you didnt upload "eduArdu Firmata" sketch, go back to previous steps to do it.

4. Click the button "Connect Arduino".

You shall see message like this:

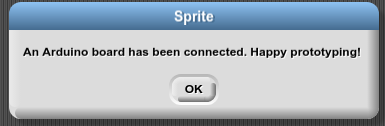
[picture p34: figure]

This means that we already set-up our eduArdu.

Go to File -> "Import...", a dialogue windows must appear. Choose eduArdu.xml file that is in your local copy to eduArdu repository in .../SOFTWARE/Snap4Arduino_eduArdu/

If you followed these steps now you must see many more blocks than before.

Go to "Control" category blocks. Drag and drop this block into the Code pane

Go to "Arduino" category and darg "Led Matrix ShowText" block. Drop it under the "When clicked" button

Go to "Control" category again. Drag "forever" block and drop it under "Show Text" in our Code pane. Now your Code pane should look like this:

In ShowText textbox enter "Hello World!" text (without quotes).

Go to "Arduino" category. Drag "LED MATRIX ShiftLeft" block and drop it in

"forever" block. Write "1" into "ShiftLeftt" textbox

Unther"LED MATRIX ShiftLeft" block drag & drop new "wait () secs" block, from "Control" category. In the textbox write "0.1"

Now our program should look like:

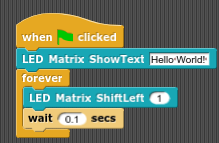
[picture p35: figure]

When you click on the green flag, the LED MATRIX of eduArdu block should start scrolling "Hello World".

III. Part - Saving a project

We can save our project in two ways:
- Saving our project on our PC

- Saving it in ".xml" file.

Choosing the first option, our project would be saved int DB, and we can not see it as standalone file.

Choosing the ".xml" option all block library, our sketch in the Code pane and everything we have done would be saved. If we later load that xml file we would not have to include libraries, that we used in that project.

How to save our project?

1. Click on "File" menu.

2. Choose "Save As" sub-menu.

3. From the dialogue window click on the "Browser" button.

4. Set project name and click "Save Project"

Hint: We can load later our project faster if we click on File menu, and double click onthe Project Name.

To save your project into ".xml" file:

1. Click on |File" menu.

2. Choose "Export project" sub-menu.

3. From the dialogue window, choose the path where to store the file.

4. Click "Save"

(https://github.com/OLIMEX/eduArdu)

In case you want to contribute or edit this file, you can find it at

https://github.com/OLIMEX/eduArdu

This documents is saved in ODT and PDF files

List of changes:

1.0 - initial version from Kaloyan Nedyalkov – Olimex LTD

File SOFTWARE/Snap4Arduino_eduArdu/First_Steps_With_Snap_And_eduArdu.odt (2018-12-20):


Първи стъпки със "Snap4Arduino"

Създай своя "Snap" за eduArdu


версия 1.0/20.12.2018

Copyright© 2018, OLIMEX Ltd

Released under CC-SA-BY-3.0 (https://creativecommons.org/licenses/by-sa/3.0/)

I. Част - Подготовка:

1. Какво представлява "Snap4Arduino" ?

- Това е модифицирана версия на Snap! (https://snap.berkeley.edu/) - визуален език за програмиране, който позволява комуникацията с почти всички Arduino базирани платки.

- Интерактивен софтуер, с чиято помощ всеки начинаещ в програмирането и Arduino може да си състави своя програма, без да има конкретни знания в областта на програмирането. Използвайки примитиви-блокчета, програмирането със Snap4Arduino е като нареждане на пъзел.

2. Какво ни трябва, за да ползваме Snap4Arduino ?

- Инсталирано ArduinoIDE

- Инсталиран Snap4Arduino

- Копие на eduArdu Github хранилище (не е задължително)

2.1 Как да инсталираме Arduino IDE ?

- Ако нямате инсталиран Arduino IDE софтуер, отидете на

https://www.arduino.cc/en/Main/Software

- Изберете подходящ инсталатор, според операционната система и версията й инсталирана на Вашият компютър.

- Стартирайте инсталатора и следвайте стъпките.

2.2 Как да инсталираме Snap4Arduino ?

- Отидете на http://snap4arduino.rocks/

- От менютата най-горе изберете "Download"

- Изберете подходящия инсталатор, според операционната

- Стартирайте Snap4Arduino инсталатора / разхархивирайте Snap4Arduino

2.3. Как да клонираме eduArdu Github repository ?

- Отидете на https://github.com/OLIMEX/eduArdu

- Клонирайте repository-то чрез GIT или щракнете на бутона

"Clone or download" -> Download ZIP

2.4. Как да заредим eduArdu Firmata?

- Отворете клонираното хранилище или разархивирайте сваления ZIP файл и влезте в директорията:

/SOFTWARE/Snap4Arduino_eduArdu/eduArdu_Firmata/

- Отворете "eduArdu_Firmata.ino".

- Трябва да се заредят всички библиотеки от /SOFTWARE/libraries/

За целта щракнете менюто "Sketch" и от под-менюто "Include Library" изберете "Add .ZIP library"


Посочете пътя до библиотеката и я заредете. Тази процедура се повтаря за всяка библиотека в "/libraries/"

2.5. Когато заредите всички библиотеки натиснете бутона за качване:

Библиотеките се зареждат еднократно и при повторно качване на eduArdu Firmata

II част - Разучаване на Snap4Arduino

Стартирайте Snap4Arduino приложението.

Трябва интерфейсът да изглежда като на снимката.


Кратко описание на различните компоненти:

1. Категории блокове. Всяка категория съдържа различни блокчета, всяко от което извършва различно действие. По отношение общите признация на блокчетата категориите биват:

- Motion - Блокчетата в тази категория извършват движение върху рисунките (Sprites)

- Looks - изкарват балончета с надписи

- Sound - възпроизвеждат звуци през високоговорителите на компютъра

- Pen - управлява моливчето (на 4. е изобразено като стрелкичка).

- Control - блокчета за извикване на функции, стартиране/спиране на програма, изчакване, проверки, цикли. С тях започваме и завършваме програмата.

- Operators - блокове за извършване на различни операции (оператори). Чрез тях можем да извършваме аритметически и логически действия, да изпълняваме JavaScript код, да правим преобразуване на формата на данните.

- Variables - това са блокове за създаване и манипулиране на променливи.

- Arduino - това са всички блокове, които са пряко свързани с периферията на Arduino. С тяхна помощ, можем да четем цифрови/аналогови входове, да сменяме състоянието/стойността на цифров/аналогов изход, да се свързваме и откачаме към/от Arduino и други.

- Other - По подразбиране в тази категория няма блокове, но ако решим да създаваме свои, които не отговарят на никоя от гореспоменатите категории, можем да ги сложим в тази.

2. Блокове.

Блоковете биват 3 основни типа.

Command блоковете изпълняват някаква функция и продължават дествието на програмата.

Reporter блоковете при изпълнение връщат резултат, който може да се използва като вход за данни на друг блок. Те не могат да се използват самостоятелно, винаги трябва да бъдат поставени в друг блок.

Predicate блоковете са подобни на Reporter, но като резултат връщат True/False (Истина/Неистина)

Блоковете могат да изпълняват функцията си самостоятелно, като щракнем върху техния примитив или да бъдат включени, като част от програма. Тогава тяхното изпълнение и резултат ще зависят от цялата програма.

Command блоковете могат да се вмъкват между блокове.

Всички блокове или множества от блокове могат да се дублират. Така няма нужда всеки път да нареждаме една и съща комбинация, за да я реплицираме.

Комплексните блокове или тези, които сме създали ние, могат да се променят. За целта натискаме десен бутон върху блока и от менюто избираме edit:


3. Поле за съставяне на програмата - в това поле нареждаме блокчетата по желания от нас начин и така съставяме програмата. В това поле ще ни се появяват и повечето диалогови прозорци.


4. Екран - екранът служи да се генерират и визуализират изображения и/или анимации. Блоковете от типа "Motion", "Looks", "Sensing", "Pen" ще придвижват курсора на екрана, сменят цвета на различните обекти, изчертават рисунки и местят изображения.

5. Менюта

Отляво надясно - Файл, Облак, Настройки.

- Файловото меню позволява създаване/отваряне на проект, записване на проект/блокове в ".xml" файл, добавяне на библиотеки и т.н.

- "Облак" менюто ни позволява да се аутентифицираме в облака на Snap4Arduino или да си създадем регистрация.

- Блокът с настройки ни дава възможност да променяме настройки по графичния интерфейс, както и да пускаме или спираме услуги.

III. част - "Hello World"

Нека включим свържем нашето eduArdu с MicroUSB кабел към компютъра.

Стартираме програмата "Snap4Arduino" и от категориите блокове избираме "Arduino".


Ако не сте качили чрез Arduino IDE програмата "eduArdu Firmata", то погледнете в началото как да го направите. След това натиснете бутона
"Connect Arduino".

В средата на екрана трябва да видим съобщение подобно на това:


Което означава, че Snap4Arduino вече е свързана с нашето eduArdu и можем да започнем да програмираме.

Нека от файловото меню изберем "Import..." и от диалоговия прозорец изберем, eduArdu.xml файла, който се намира в нашето копие на eduArdu repository и по-точно в .../SOFTWARE/Snap4Arduino_eduArdu/

Ако сте изпълнили всичко правилно трябва след зареждането на файла да се появят нови блокчета в Arduino категорията.

Щракнете на категория "Control" С влачене вземете блокчето

и го поставете в полето за съставяне на програмата.

По същия начин, от категория "Arduino" избираме блокчето "Led Matrix ShowText" и го завличаме така, че да се съедини с блокчето, което завлякохме преди малко.

Сега натискаме отново "Control" категорията. Оттам взимаме блокчето "forever"

и го завличаме и съединяваме с блокчето "Show Text". Трябва да се получи пъзел от 3 елемента:

в полето ShowText пишем "Hello World! " (Без кавичките).

от "Arduino" категорията взимаме блокчето с надпис "LED MATRIX ShiftLeft"

и го слагаме в блокчето "forever". Вътре в полето пишем "1" (без кавички)

Под блокчето "LED MATRIX ShiftLeft" поставяме блокчето "wait () secs", което се намира в категория "Control". В неговото поле пишем "0.1"

Резултатът трябва да бъде:


Когато натиснем зеленото флагче в горния десен ъгъл на програмата или върху най-горното блокче от пъзела, на светодиодната матрица трябва да започне да се движи надписа "Hello World"

III. Част - Запазване на проект

За да запазим проекта си на нашия компютър имаме две възможности.
- Да запишем проекта на компютъра

- Да го съхраним в ".xml" формат.

Когато изберем първата опция, проектът се съхранява в локална база, като той не съществува като самостоятелен файл.

При съхраняване на проекта, всички блокове, които сме заредили, заедно с тези, които сме използвали, както и програмата, която сме съставили се запазват в един файл. Така например, при затваряне на програмата и отварянето й по-късно, когато отворим съхранения ".xml" файл или проекта, съхранен на компютъра, няма нужда да добавяме допълнителните блокове от "eduArdu.xml" файла.

За да запишем проекта на компютъра:

1. Щракваме върху файловото меню.

2. Избираме Save As.

3. От диалоговия прозорец избираме иконката "Browser".

4. Задаваме име на проекта и натискаме Save Project

За да отворим проекта по-късно, избираме от файловото меню Open и щракваме два пъти върху името на проекта.

За да извлечем проекта в ".xml" формат:

1. Щракваме върху файловото меню.

2. Избираме Export project.

3. От диалоговия прозорец избираме името и пътя на файла, който искаме да запишем.

4. Натискаме Save

Този документ се съхранява в ODT и PDF формат на https://github.com/OLIMEX/eduArdu в случай че желаете да вземете участие и да усъвършенствате, редактирате, подобрите или просто да добавите нещо в него.

Списък на промените:

1.0 - първоначална версия от Калоян Иванов – Олимекс ООД

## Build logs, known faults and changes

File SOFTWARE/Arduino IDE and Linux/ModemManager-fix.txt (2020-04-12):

Feedback by Leon Anavi:

On Ubuntu 18.04.4 LTS following error is shown when uploading from Arduno IDE:

avrdude: Expected signature for ATmega32U4 is 1E 95 87

The solution is to stop modemmanager:

systemctl stop ModemManager

More details: https://github.com/arduino/Arduino/issues/7690

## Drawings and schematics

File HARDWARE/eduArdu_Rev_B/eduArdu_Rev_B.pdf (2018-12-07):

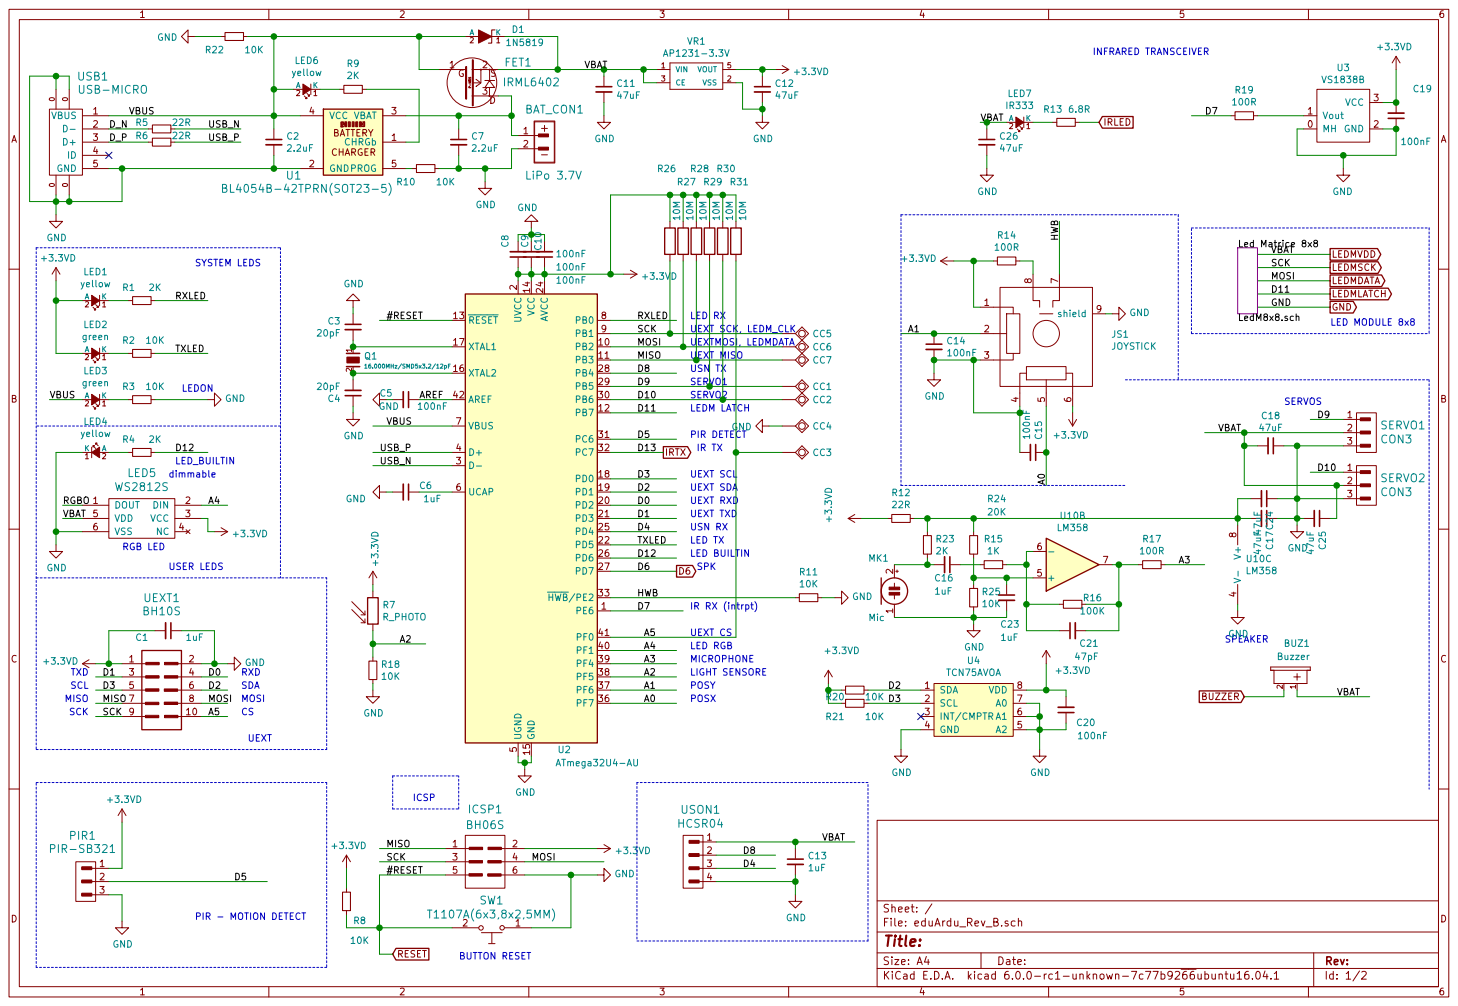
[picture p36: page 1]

SYSTEM LEDS USER LEDS

LED MODULE 8x8 VBAT GND
SCK MOSI D11

2 PD2 20 PD3 21 PD5 22 AVCC 24 PD4 25 PD6 26 PD7 27 PB4 28 PB5 29 D- 3 PB6 30 PC6 31 PC7 32 HWB/PE2 33 PF7 36 PF6 37 PF5 38 PF4 39 D+ 4 PF1 40 PF0 41 AREF 42 UGND

1 BUZ1 Buzzer UEXT SCK, LEDM_CLK UEXTMOSI, LEDMDATA UEXT MISO

UEXT SCL UEXT SDA MISO

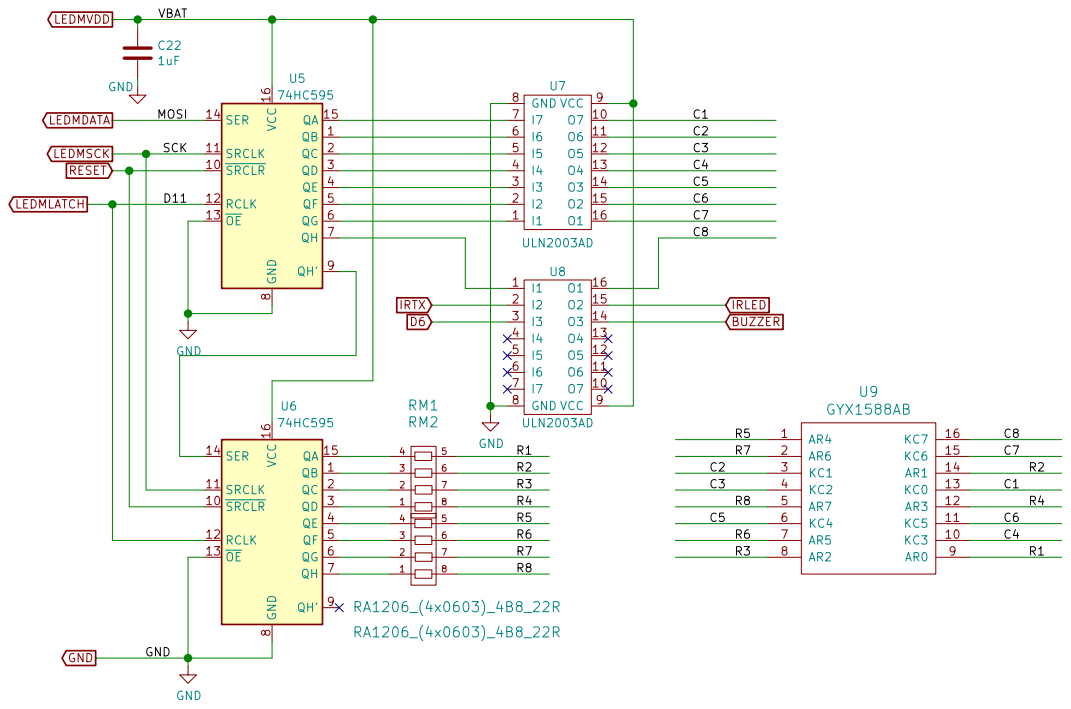
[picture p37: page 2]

I6 6
I5 5
I4 4
I3 3

Id: 2/2 Title: File: LedM8x8.sch Sheet: /Led Matrice 8x8/

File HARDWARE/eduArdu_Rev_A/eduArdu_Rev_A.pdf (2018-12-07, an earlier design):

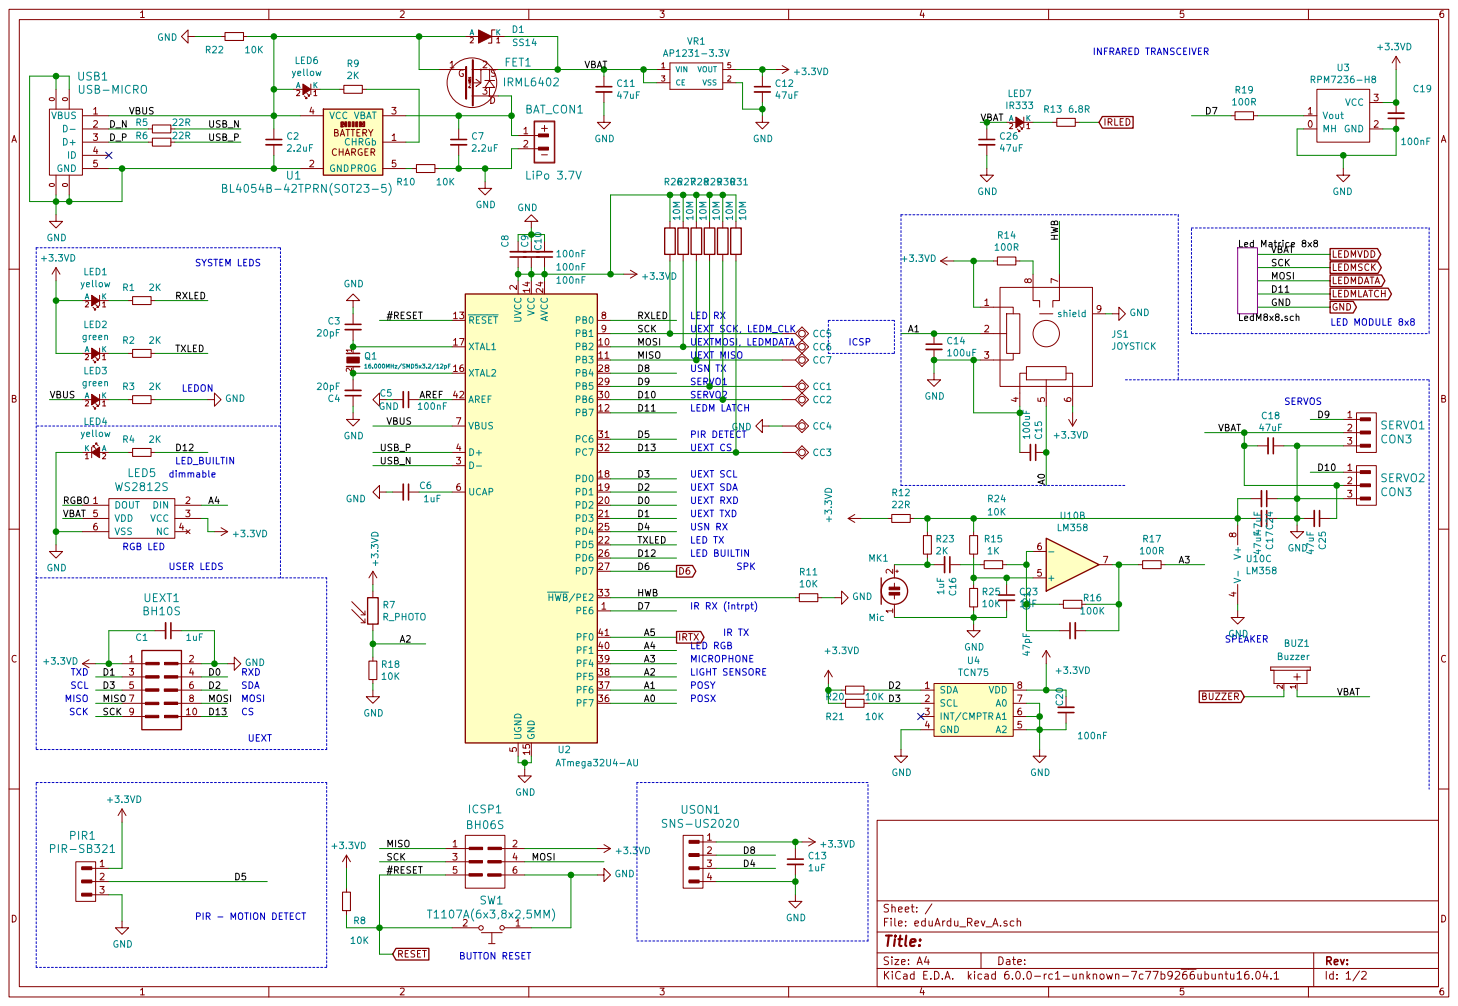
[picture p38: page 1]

SYSTEM LEDS USER LEDS

LED MODULE 8x8 VBAT GND
SCK MOSI D11

2 PD2 20 PD3 21 PD5 22 AVCC 24 PD4 25 PD6 26 PD7 27 PB4 28 PB5 29 D- 3 PB6 30 PC6 31 PC7 32 HWB/PE2 33 PF7 36 PF6 37 PF5 38 PF4 39 D+ 4 PF1 40 PF0 41 AREF 42 UGND

1 BUZ1 Buzzer UEXT SCK, LEDM_CLK UEXTMOSI, LEDMDATA UEXT MISO

UEXT SCL UEXT SDA MISO

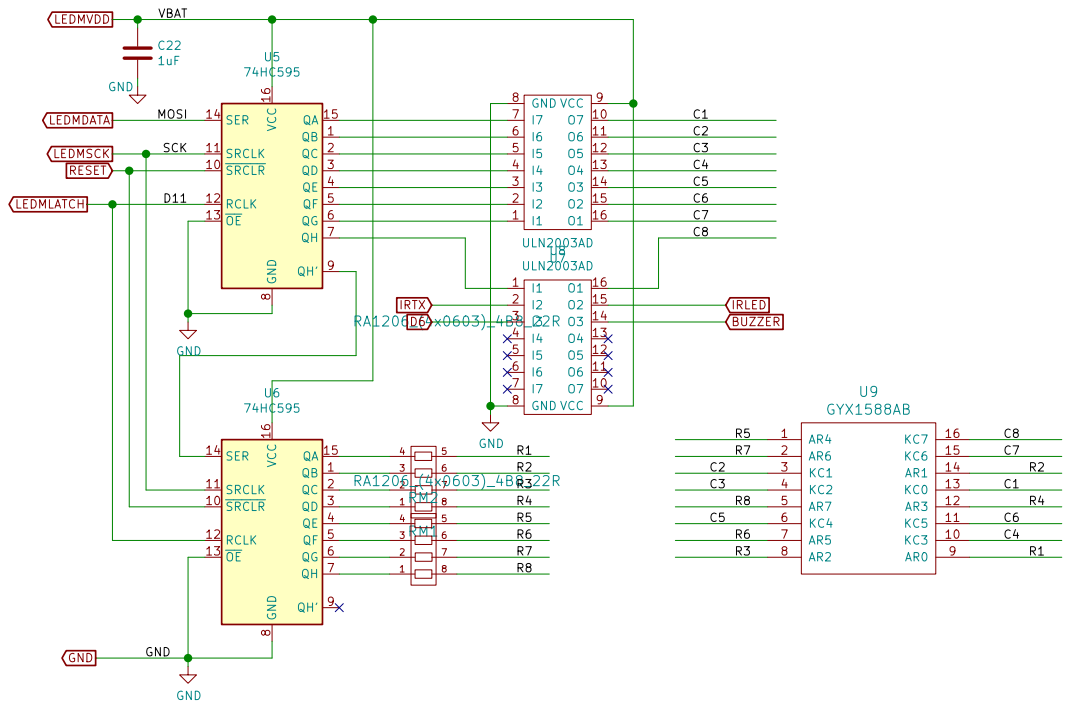
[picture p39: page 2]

I6 6
I5 5
I4 4
I3 3

Id: 2/2 Title: File: LedM8x8.sch Sheet: /Led Matrice 8x8/

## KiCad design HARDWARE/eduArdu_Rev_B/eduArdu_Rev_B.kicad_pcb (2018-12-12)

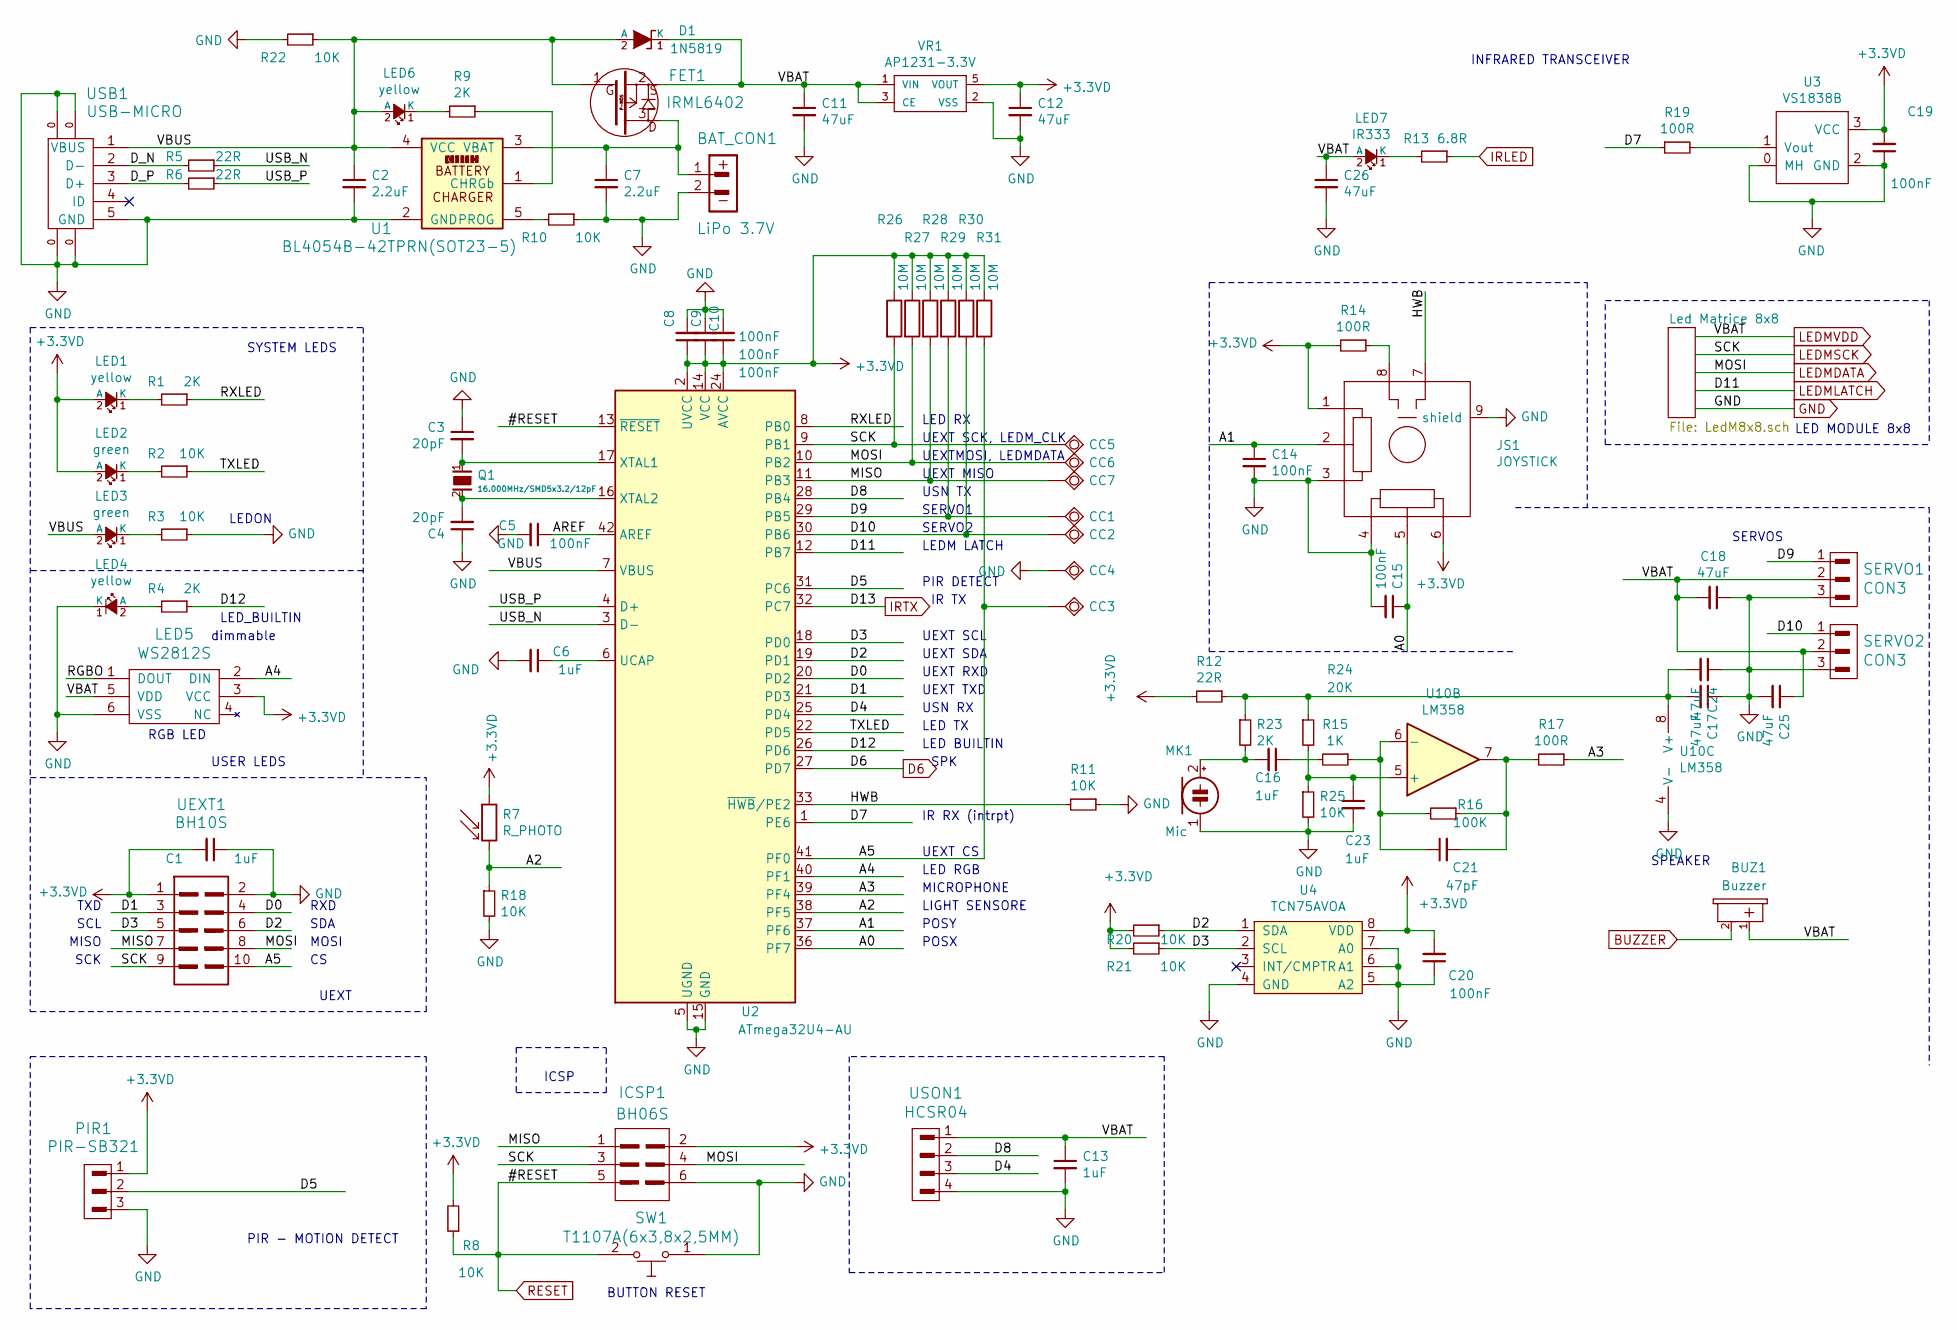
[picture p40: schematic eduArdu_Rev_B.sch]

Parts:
BAT_CON1: LiPo 3.7V; LIPO_BAT-CON2DW02R
BUZ1: Buzzer; BUZZER-PB1240
C1, C6, C13, C16, C23: 1uF; C_0603_5MIL_DWS
C2, C7: 2.2uF; C_0603_5MIL_DWS
C3, C4: 20pF; C_0402_5MIL_DWS
C5, C8, C9, C10, C14, C15, C19, C20: 100nF; C_0402_5MIL_DWS
C11, C12, C18, C26: 47uF; C_0805_5MIL_DWS
C17, C24, C25: 47uF; C_0603_5MIL_DWS
C21: 47pF; C_0402_5MIL_DWS
CC1, CC2, CC3, CC4, CC5, CC6, CC7: TESTPAD; Mounting_hole_Shield_4.3mm
D1: 1N5819; SMA-KA
FET1: IRML6402; SOT23
ICSP1: BH06S; HN2x3
JS1: JOYSTICK
LED1, LED4, LED6: yellow; LED_0603_KA
LED2, LED3: green; LED_0603_KA
LED5: WS2812S; WS2812_NO_SILK
LED7: IR333; LED-5mm-PTH-AK
MK1: Mic; MIC
PIR1: PIR-SB321; HN1x3
Q1: 16.000MHz/SMD5x3.2/12pF; HCX-4S_2Pins_5.0x3.2mm
R1, R4, R9, R23: 2K; R_0402_5MIL_DWS
R2, R3, R8, R10, R11, R18, R20, R21, R22, R25: 10K; R_0402_5MIL_DWS
R5, R6, R12: 22R; R_0402_5MIL_DWS
R7: R_PHOTO
R13: 6.8R; R_1206_5MIL_DWS
R14, R17, R19: 100R; R_0402_5MIL_DWS
R15: 1K; R_0402_5MIL_DWS
R16: 100K; R_0402_5MIL_DWS
R24: 20K; R_0402_5MIL_DWS
R26, R27, R28, R29, R30, R31: 10M; R_0402_5MIL_DWS
SERVO1, SERVO2: CON3; HN1x3
SW1: T1107A(6x3,8x2,5MM)
U1: BL4054B-42TPRN(SOT23-5); SOT-23-5
U2: ATmega32U4-AU; TQFP44
U3: VS1838B; RPM7236-H8-V
U4: TCN75AVOA; SO-8
U10: LM358; SO-8
UEXT1: BH10S; UEXTM-SMD
USB1: USB-MICRO; MICRO_USB_5P-F_TYPE_DIP
USON1: HCSR04; USONIC-PING
VR1: AP1231-3.3V; SOT-23-5

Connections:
+3.3VD: C1.2, C8.1, C9.1, C10.1, C12.1, C19.2, C20.2, ICSP1.2, JS1.1, JS1.6, LED1.2 (A), LED2.2 (A), LED5.3 (VCC), PIR1.1, R7.1, R8.2, R12.2, R14.2, R20.2, R21.2, R26.1, R27.1, R28.1, R29.1, R30.1, R31.1, U2.2 (UVCC), U2.14 (VCC), U2.24 (AVCC), U2.34 (VCC), U2.44 (AVCC), U3.3 (VCC), U4.8 (VDD), UEXT1.1, VR1.5 (VOUT)
/A0: C15.1, JS1.5, U2.36 (PF7)
/A1: C14.1, JS1.2, U2.37 (PF6)
/A2: R7.2, R18.1, U2.38 (PF5)
/A3: R17.1, U2.39 (PF4)
/A4: LED5.2 (DIN), U2.40 (PF1)
/A5: CC3.1, R31.2, U2.41 (PF0), UEXT1.10
/AREF: C5.1, U2.42 (AREF)
/D0: U2.20 (PD2), UEXT1.4
/D1: U2.21 (PD3), UEXT1.3
/D2: R20.1, U2.19 (PD1), U4.1 (SDA), UEXT1.6
/D3: R21.1, U2.18 (PD0), U4.2 (SCL), UEXT1.5
/D4: U2.25 (PD4), USON1.3
/D5: PIR1.2, U2.31 (PC6)
/D7: R19.1, U2.1 (PE6)
/D8: U2.28 (PB4), USON1.2
/D9: CC1.1, R29.2, SERVO1.1, U2.29 (PB5)
/D10: CC2.1, R30.2, SERVO2.1, U2.30 (PB6)
/D12: R4.1, U2.26 (PD6)
/D_N: R5.2, USB1.2 (D-)
/D_P: R6.2, USB1.3 (D+)
/HWB: JS1.7, R11.2, U2.33 (~HWB~/PE2)
/MISO: CC7.1, ICSP1.1, R28.2, U2.11 (PB3), UEXT1.7
/RGBO: LED5.1 (DOUT)
/RXLED: R1.1, U2.8 (PB0)
/TXLED: R2.1, U2.22 (PD5)
/USB_N: R5.1, U2.3 (D-)
/USB_P: R6.1, U2.4 (D+)
/VBUS: C2.1, D1.2 (A), FET1.1, LED3.2 (A), LED6.2 (A), R22.1, U1.4 (VCC), U2.7 (VBUS), USB1.1 (VBUS)
BUZZER: BUZ1.2 (MINUS); also elsewhere on the board
D6: U2.27 (PD7); also elsewhere on the board
GND: BAT_CON1.2, C1.1, C2.2, C3.1, C4.1, C5.2, C6.2, C7.2, C8.2, C9.2, C10.2, C11.2, C12.2, C13.2, C14.2, C15.2, C17.1, C18.1, C19.1, C20.1, C23.2, C24.1, C25.2, C26.2, CC4.1, ICSP1.6, JS1.3, JS1.4, JS1.9 (shield), LED4.1 (K), LED5.6 (VSS), MK1.1 (-), PIR1.3, R3.1, R10.1, R11.1, R18.2, R22.2, R25.2, SERVO1.3, SERVO2.3, SW1.1, U1.2 (GND), U2.5 (UGND), U2.15 (GND), U2.23 (GND), U2.35 (GND), U2.43 (GND), U3.0 (MH), U3.2 (GND), U4.4 (GND), U4.5 (A2), U4.6 (A1), U4.7 (A0), U10.4 (V-), UEXT1.2, USB1.0, USB1.5 (GND), USON1.4, VR1.2 (VSS); also elsewhere on the board
IRLED: R13.1; also elsewhere on the board
IRTX: U2.32 (PC7); also elsewhere on the board
LEDMDATA: CC6.1, ICSP1.4, R27.2, U2.10 (PB2), UEXT1.8; also elsewhere on the board
LEDMLATCH: U2.12 (PB7); also elsewhere on the board
LEDMSCK: CC5.1, ICSP1.3, R26.2, U2.9 (PB1), UEXT1.9; also elsewhere on the board
LEDMVDD: BUZ1.1 (PLUS), C11.1, C13.1, C18.2, C25.1, C26.1, D1.1 (K), FET1.2, LED5.5 (VDD), LED7.2 (A), SERVO1.2, SERVO2.2, USON1.1, VR1.1 (VIN), VR1.3 (CE); also elsewhere on the board
unnamed: BAT_CON1.1, C7.1, FET1.3, U1.3 (VBAT)
unnamed: C3.2, Q1.1, U2.17 (XTAL1)
unnamed: C4.2, Q1.2, U2.16 (XTAL2)
unnamed: C6.1, U2.6 (UCAP)
unnamed: C16.1, R15.2
unnamed: C16.2, MK1.2 (+), R23.2
unnamed: C17.2, C24.2, R12.1, R23.1, R24.1, U10.8 (V+)
unnamed: C21.1, R15.1, R16.2, U10.6 (-)
unnamed: C21.2, R16.1, R17.2, U10.7
unnamed: C23.1, R24.2, R25.1, U10.5 (+)
unnamed: JS1.8, R14.1
unnamed: LED1.1 (K), R1.2
unnamed: LED2.1 (K), R2.2
unnamed: LED3.1 (K), R3.2
unnamed: LED4.2 (A), R4.2
unnamed: LED6.1 (K), R9.2
unnamed: LED7.1 (K), R13.2
unnamed: R9.1, U1.1 (CHRGb)
unnamed: R10.2, U1.5 (PROG)
unnamed: R19.2, U3.1 (Vout)
RESET: ICSP1.5, R8.1, SW1.2, U2.13 (~RESET); also elsewhere on the board

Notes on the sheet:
RXD
SDA
MOSI
TXD
SCL
MISO
SCK
LED_BUILTIN
RGB LED
dimmable
LEDON
PIR DETECT
LED TX
LED RX
LED BUILTIN
ICSP
LED RGB
POSX
POSY
BUTTON RESET
USN RX
USN TX
INFRARED TRANSCEIVER
UEXT SCL
UEXT SDA
UEXT CS
UEXT TXD
UEXT RXD
SERVO1
SERVO2
SPK
UEXT SCK, LEDM_CLK
UEXTMOSI, LEDMDATA
UEXT MISO
LEDM LATCH
LED MODULE 8x8
IR RX (intrpt)
SERVOS
SPEAKER
UEXT

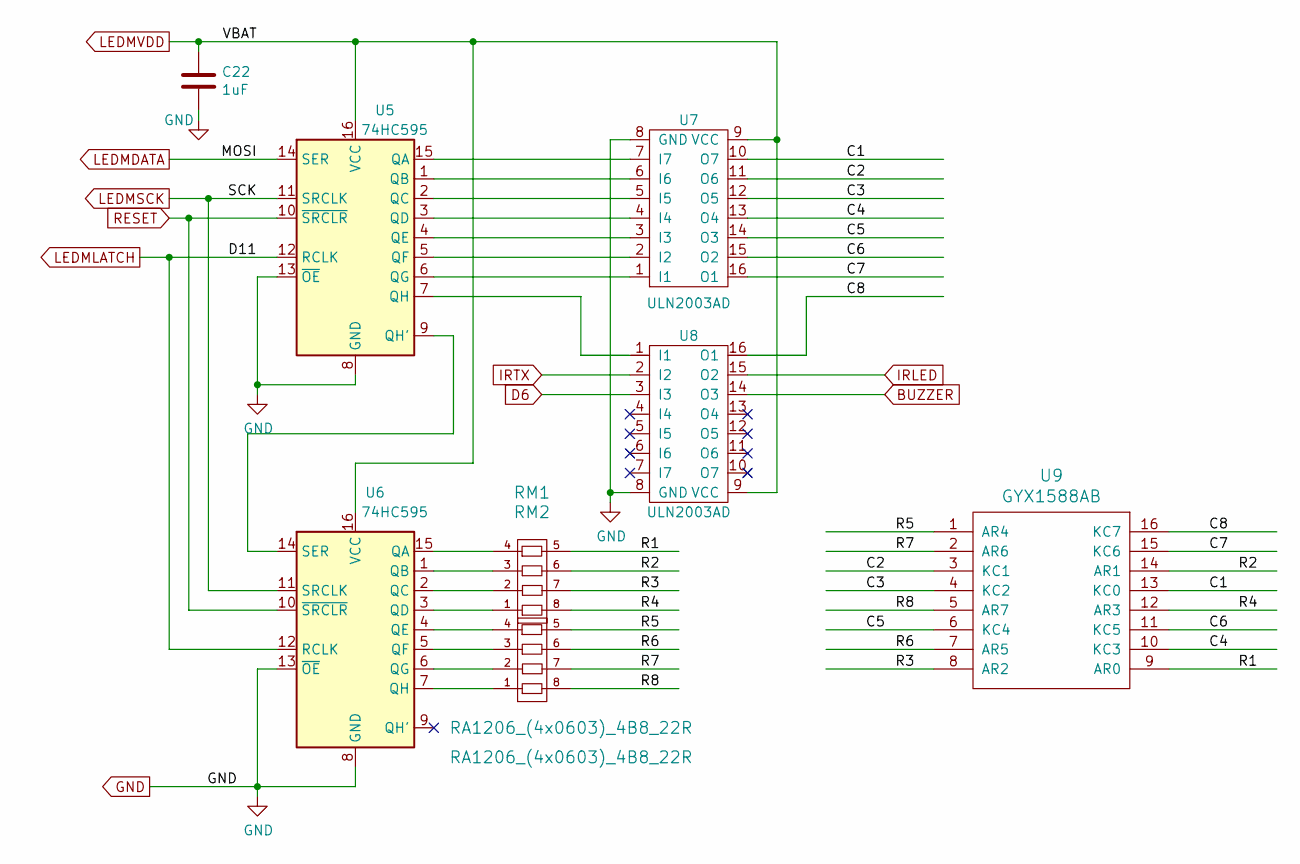
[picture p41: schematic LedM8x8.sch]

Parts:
C22: 1uF; C_0603_5MIL_DWS
RM1, RM2: RA1206_(4x0603)_4B8_22R; RA1206_(4X0603)_4B8_mine
U5, U6: 74HC595; SO-16
U7, U8: ULN2003AD; SO-16
U9: GYX1588AB

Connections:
/Led Matrice 8x8/C1: U7.10 (O7), U9.13 (KC0)
/Led Matrice 8x8/C2: U7.11 (O6), U9.3 (KC1)
/Led Matrice 8x8/C3: U7.12 (O5), U9.4 (KC2)
/Led Matrice 8x8/C4: U7.13 (O4), U9.10 (KC3)
/Led Matrice 8x8/C5: U7.14 (O3), U9.6 (KC4)
/Led Matrice 8x8/C6: U7.15 (O2), U9.11 (KC5)
/Led Matrice 8x8/C7: U7.16 (O1), U9.15 (KC6)
/Led Matrice 8x8/C8: U8.16 (O1), U9.16 (KC7)
/Led Matrice 8x8/R1: RM1.5, U9.9 (AR0)
/Led Matrice 8x8/R2: RM1.6, U9.14 (AR1)
/Led Matrice 8x8/R3: RM1.7, U9.8 (AR2)
/Led Matrice 8x8/R4: RM1.8, U9.12 (AR3)
/Led Matrice 8x8/R5: RM2.5, U9.1 (AR4)
/Led Matrice 8x8/R6: RM2.6, U9.7 (AR5)
/Led Matrice 8x8/R7: RM2.7, U9.2 (AR6)
/Led Matrice 8x8/R8: RM2.8, U9.5 (AR7)
BUZZER: U8.14 (O3); also elsewhere on the board
D6: U8.3 (I3); also elsewhere on the board
GND: C22.2, U5.8 (GND), U5.13 (~OE), U6.8 (GND), U6.13 (~OE), U7.8 (GND), U8.8 (GND); also elsewhere on the board
IRLED: U8.15 (O2); also elsewhere on the board
IRTX: U8.2 (I2); also elsewhere on the board
LEDMDATA: U5.14 (SER); also elsewhere on the board
LEDMLATCH: U5.12 (RCLK), U6.12 (RCLK); also elsewhere on the board
LEDMSCK: U5.11 (SRCLK), U6.11 (SRCLK); also elsewhere on the board
LEDMVDD: C22.1, U5.16 (VCC), U6.16 (VCC), U7.9 (VCC), U8.9 (VCC); also elsewhere on the board
unnamed: RM1.1, U6.3 (QD)
unnamed: RM1.2, U6.2 (QC)
unnamed: RM1.3, U6.1 (QB)
unnamed: RM1.4, U6.15 (QA)
unnamed: RM2.1, U6.7 (QH)
unnamed: RM2.2, U6.6 (QG)
unnamed: RM2.3, U6.5 (QF)
unnamed: RM2.4, U6.4 (QE)
unnamed: U5.1 (QB), U7.6 (I6)
unnamed: U5.2 (QC), U7.5 (I5)
unnamed: U5.3 (QD), U7.4 (I4)
unnamed: U5.4 (QE), U7.3 (I3)
unnamed: U5.5 (QF), U7.2 (I2)
unnamed: U5.6 (QG), U7.1 (I1)
unnamed: U5.7 (QH), U8.1 (I1)
unnamed: U5.9 (QH'), U6.14 (SER)
unnamed: U5.15 (QA), U7.7 (I7)
RESET: U5.10 (~SRCLR), U6.10 (~SRCLR); also elsewhere on the board

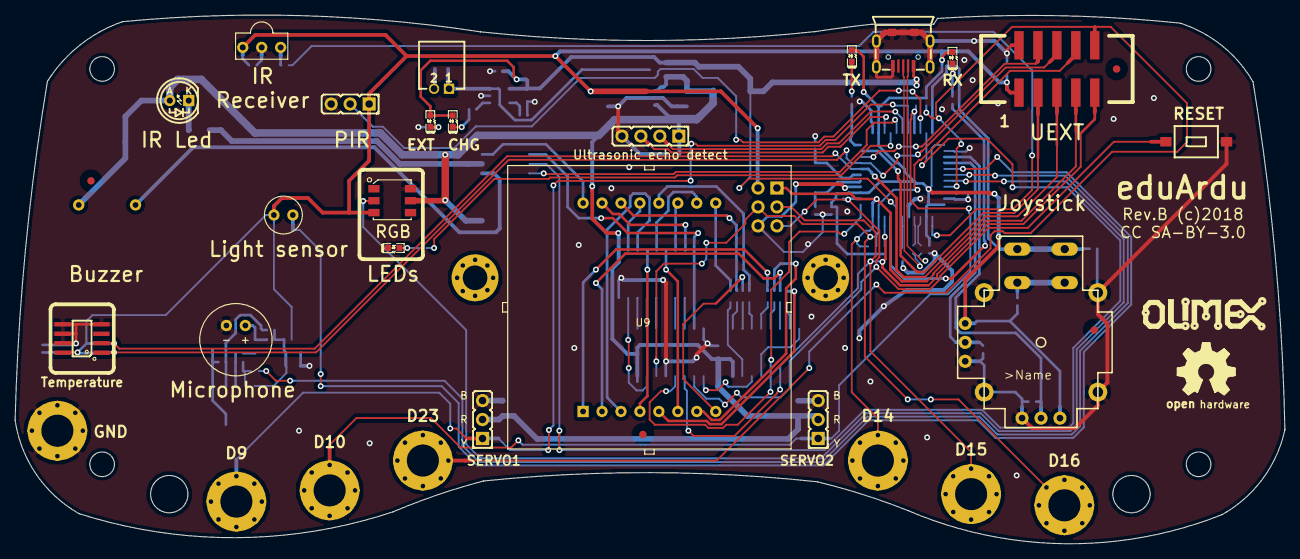
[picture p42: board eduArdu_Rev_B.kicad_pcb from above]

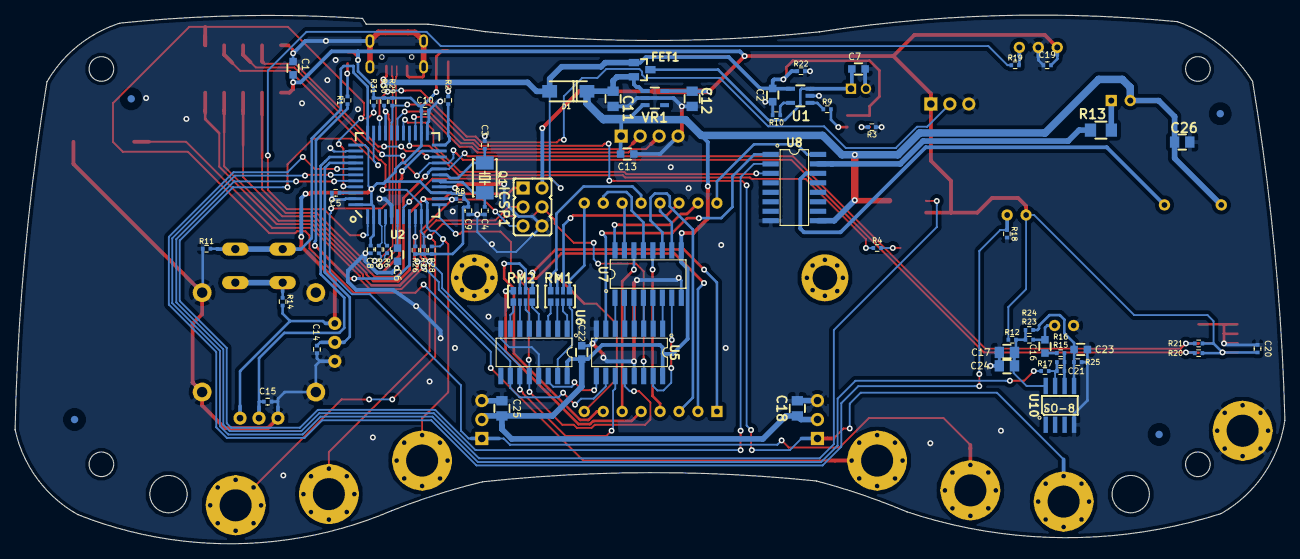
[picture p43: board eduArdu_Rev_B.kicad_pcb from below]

Board: 2 copper layers, 170.2 x 70.9 mm, 115 parts (74 on the bottom side), 91 nets.

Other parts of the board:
MountingHole: NPTH_2.7mm
MountingHole#2, MountingHole#3, MountingHole#4, MountingHole#5, MountingHole#6: NPTH_2.7mm
MountingHoleShield**: Mounting_hole_Shield_3.3mm
MountingHoleShield**#2: Mounting_hole_Shield_3.3mm
Ref*: Val**; Fiducial1x3_transp
Ref*#2, Ref*#3, Ref*#4, Ref*#5, Ref*#6, Ref*#7, Ref*#8: Val**; Fiducial1x3_transp

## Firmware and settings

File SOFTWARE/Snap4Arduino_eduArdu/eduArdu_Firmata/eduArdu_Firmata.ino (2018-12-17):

/*
 * Firmata is a generic protocol for communicating with microcontrollers
 * from software on a host computer. It is intended to work with
 * any host computer software package.
 *
 * To download a host software package, please clink on the following link
 * to open the download page in your default browser.
 *
 * http://firmata.org/wiki/Download
 */

/*
  Copyright (C) 2006-2008 Hans-Christoph Steiner.  All rights reserved.
  Copyright (C) 2010-2011 Paul Stoffregen.  All rights reserved.
  Copyright (C) 2009 Shigeru Kobayashi.  All rights reserved.
  Copyright (C) 2009-2011 Jeff Hoefs.  All rights reserved.
  This library is free software; you can redistribute it and/or
  modify it under the terms of the GNU Lesser General Public
  License as published by the Free Software Foundation; either
  version 2.1 of the License, or (at your option) any later version.
  See file LICENSE.txt for further informations on licensing terms.
  formatted using the GNU C formatting and indenting
*/

/*
 * TODO: use Program Control to load stored profiles from EEPROM
 */

#include <Servo.h>
#include <Wire.h>
#include <Firmata.h>
#include <Adafruit_NeoPixel.h>
#include <Ultrasonic.h>
#include <string.h>
#include <LED_Matrix.h>
#include <font.h>


// LED Matrix pins
#define LED_LATCH 11
#define LED_DATA 16
#define LED_CLOCK 15

//RGB LED pinout
#define RGB_PIN A4



// move the following defines to Firmata.h?
#define I2C_WRITE B00000000
#define I2C_READ B00001000
#define I2C_READ_CONTINUOUSLY B00010000
#define I2C_STOP_READING B00011000
#define I2C_READ_WRITE_MODE_MASK B00011000
#define I2C_10BIT_ADDRESS_MODE_MASK B00100000

#define MAX_QUERIES 8
#define MINIMUM_SAMPLING_INTERVAL 10

#define REGISTER_NOT_SPECIFIED -1

/*==============================================================================
 * GLOBAL VARIABLES
 *============================================================================*/

int showMatrix = 0;
/* Ultrasonig module */

/* Led matrix module */
LED_Matrix Matrix(LED_LATCH,LED_DATA,LED_CLOCK);
/* RGB LED */
Adafruit_NeoPixel RGB_LED = Adafruit_NeoPixel(1, A4, NEO_GRB + NEO_KHZ800);

/* analog inputs */
int analogInputsToReport = 0; // bitwise array to store pin reporting

/* digital input ports */
byte reportPINs[TOTAL_PORTS];       // 1 = report this port, 0 = silence
byte previousPINs[TOTAL_PORTS];     // previous 8 bits sent

/* pins configuration */
byte pinConfig[TOTAL_PINS];         // configuration of every pin
byte portConfigInputs[TOTAL_PORTS]; // each bit: 1 = pin in INPUT, 0 = anything else
int pinState[TOTAL_PINS];           // any value that has been written

/* timer variables */
unsigned long currentMillis;        // store the current value from millis()
unsigned long previousMillis;       // for comparison with currentMillis
int samplingInterval = 19;          // how often to run the main loop (in ms)
int duration = 0;
int distance = 0;
/* i2c data */
struct i2c_device_info {
  byte addr;
  byte reg;
  byte bytes;
};

/* for i2c read continuous more */
i2c_device_info query[MAX_QUERIES];

byte i2cRxData[32];
boolean isI2CEnabled = false;
signed char queryIndex = -1;
unsigned int i2cReadDelayTime = 0;  // default delay time between i2c read request and Wire.requestFrom()
Servo servos[MAX_SERVOS];
/*==============================================================================
 * FUNCTIONS
 *============================================================================*/

void readAndReportData(byte address, int theRegister, byte numBytes) {
  // allow I2C requests that don't require a register read
  // for example, some devices using an interrupt pin to signify new data available
  // do not always require the register read so upon interrupt you call Wire.requestFrom()
  if (theRegister != REGISTER_NOT_SPECIFIED) {
    Wire.beginTransmission(address);
#if ARDUINO >= 100
    Wire.write((byte)theRegister);
#else
    Wire.send((byte)theRegister);
#endif
    Wire.endTransmission();
    // do not set a value of 0
    if (i2cReadDelayTime > 0) {
      // delay is necessary for some devices such as WiiNunchuck
      delayMicroseconds(i2cReadDelayTime);
    }
  } else {
    theRegister = 0;  // fill the register with a dummy value
  }

  Wire.requestFrom(address, numBytes);  // all bytes are returned in requestFrom

  // check to be sure correct number of bytes were returned by slave
  if (numBytes == Wire.available()) {
    i2cRxData[0] = address;
    i2cRxData[1] = theRegister;
    for (int i = 0; i < numBytes; i++) {
#if ARDUINO >= 100
      i2cRxData[2 + i] = Wire.read();
#else
      i2cRxData[2 + i] = Wire.receive();
#endif
    }
  }
  else {
    if (numBytes > Wire.available()) {
      Firmata.sendString("I2C Read Error: Too many bytes received");
    } else {
      Firmata.sendString("I2C Read Error: Too few bytes received");
    }
  }

  // send slave address, register and received bytes
  Firmata.sendSysex(SYSEX_I2C_REPLY, numBytes + 2, i2cRxData);
}

void outputPort(byte portNumber, byte portValue, byte forceSend)
{
  // pins not configured as INPUT are cleared to zeros
  portValue = portValue & portConfigInputs[portNumber];
  // only send if the value is different than previously sent
  if (forceSend || previousPINs[portNumber] != portValue) {
    Firmata.sendDigitalPort(portNumber, portValue);
    previousPINs[portNumber] = portValue;
  }
}

/* -----------------------------------------------------------------------------
 * check all the active digital inputs for change of state, then add any events
 * to the Serial output queue using Serial.print() */
void checkDigitalInputs(void)
{
  /* Using non-looping code allows constants to be given to readPort().
   * The compiler will apply substantial optimizations if the inputs
   * to readPort() are compile-time constants. */
  if (TOTAL_PORTS > 0 && reportPINs[0]) outputPort(0, readPort(0, portConfigInputs[0]), false);
  if (TOTAL_PORTS > 1 && reportPINs[1]) outputPort(1, readPort(1, portConfigInputs[1]), false);
  if (TOTAL_PORTS > 2 && reportPINs[2]) outputPort(2, readPort(2, portConfigInputs[2]), false);
  if (TOTAL_PORTS > 3 && reportPINs[3]) outputPort(3, readPort(3, portConfigInputs[3]), false);
  if (TOTAL_PORTS > 4 && reportPINs[4]) outputPort(4, readPort(4, portConfigInputs[4]), false);
  if (TOTAL_PORTS > 5 && reportPINs[5]) outputPort(5, readPort(5, portConfigInputs[5]), false);
  if (TOTAL_PORTS > 6 && reportPINs[6]) outputPort(6, readPort(6, portConfigInputs[6]), false);
  if (TOTAL_PORTS > 7 && reportPINs[7]) outputPort(7, readPort(7, portConfigInputs[7]), false);
  if (TOTAL_PORTS > 8 && reportPINs[8]) outputPort(8, readPort(8, portConfigInputs[8]), false);
  if (TOTAL_PORTS > 9 && reportPINs[9]) outputPort(9, readPort(9, portConfigInputs[9]), false);
  if (TOTAL_PORTS > 10 && reportPINs[10]) outputPort(10, readPort(10, portConfigInputs[10]), false);
  if (TOTAL_PORTS > 11 && reportPINs[11]) outputPort(11, readPort(11, portConfigInputs[11]), false);
  if (TOTAL_PORTS > 12 && reportPINs[12]) outputPort(12, readPort(12, portConfigInputs[12]), false);
  if (TOTAL_PORTS > 13 && reportPINs[13]) outputPort(13, readPort(13, portConfigInputs[13]), false);
  if (TOTAL_PORTS > 14 && reportPINs[14]) outputPort(14, readPort(14, portConfigInputs[14]), false);
  if (TOTAL_PORTS > 15 && reportPINs[15]) outputPort(15, readPort(15, portConfigInputs[15]), false);
}

// -----------------------------------------------------------------------------
/* sets the pin mode to the correct state and sets the relevant bits in the
 * two bit-arrays that track Digital I/O and PWM status
 */
void setPinModeCallback(byte pin, int mode)
{
  if (pinConfig[pin] == I2C && isI2CEnabled && mode != I2C) {
    // disable i2c so pins can be used for other functions
    // the following if statements should reconfigure the pins properly
    disableI2CPins();
  }
  if (IS_PIN_SERVO(pin) && mode != SERVO && servos[PIN_TO_SERVO(pin)].attached()) {
    servos[PIN_TO_SERVO(pin)].detach();
  }
  if (IS_PIN_ANALOG(pin)) {
    reportAnalogCallback(PIN_TO_ANALOG(pin), mode == ANALOG ? 1 : 0); // turn on/off reporting
  }
  if (IS_PIN_DIGITAL(pin)) {
    if (mode == INPUT) {
      portConfigInputs[pin / 8] |= (1 << (pin & 7));
    } else {
      portConfigInputs[pin / 8] &= ~(1 << (pin & 7));
    }
  }
  pinState[pin] = 0;
  switch (mode) {
    case ANALOG:
      if (IS_PIN_ANALOG(pin)) {
        if (IS_PIN_DIGITAL(pin)) {
          pinMode(PIN_TO_DIGITAL(pin), INPUT); // disable output driver
          digitalWrite(PIN_TO_DIGITAL(pin), LOW); // disable internal pull-ups
        }
        pinConfig[pin] = ANALOG;
      }
      break;
    case INPUT:
      if (IS_PIN_DIGITAL(pin)) {
        pinMode(PIN_TO_DIGITAL(pin), INPUT); // disable output driver
        digitalWrite(PIN_TO_DIGITAL(pin), LOW); // disable internal pull-ups
        pinConfig[pin] = INPUT;
      }
      break;
    case OUTPUT:
      if (IS_PIN_DIGITAL(pin)) {
        digitalWrite(PIN_TO_DIGITAL(pin), LOW); // disable PWM
        pinMode(PIN_TO_DIGITAL(pin), OUTPUT);
        pinConfig[pin] = OUTPUT;
      }
      break;
    case PWM:
      if (IS_PIN_PWM(pin)) {
        pinMode(PIN_TO_PWM(pin), OUTPUT);
        analogWrite(PIN_TO_PWM(pin), 0);
        pinConfig[pin] = PWM;
      }
      break;
    case SERVO:
      if (IS_PIN_SERVO(pin)) {
        pinConfig[pin] = SERVO;
        if (!servos[PIN_TO_SERVO(pin)].attached()) {
          servos[PIN_TO_SERVO(pin)].attach(PIN_TO_DIGITAL(pin));
        }
      }
      break;
    case I2C:
      if (IS_PIN_I2C(pin)) {
        // mark the pin as i2c
        // the user must call I2C_CONFIG to enable I2C for a device
        pinConfig[pin] = I2C;
      }
      break;
    default:
      Firmata.sendString("Unknown pin mode"); // TODO: put error msgs in EEPROM
  }
  // TODO: save status to EEPROM here, if changed
}

void analogWriteCallback(byte pin, int value)
{
  if (pin < TOTAL_PINS) {
    switch (pinConfig[pin]) {
      case SERVO:
        if (IS_PIN_SERVO(pin))
          servos[PIN_TO_SERVO(pin)].write(value);
        pinState[pin] = value;
        break;
      case PWM:
        if (IS_PIN_PWM(pin))
          analogWrite(PIN_TO_PWM(pin), value);
        pinState[pin] = value;
        break;
    }
  }
}

void digitalWriteCallback(byte port, int value)
{
  byte pin, lastPin, mask = 1, pinWriteMask = 0;

  if (port < TOTAL_PORTS) {
    // create a mask of the pins on this port that are writable.
    lastPin = port * 8 + 8;
    if (lastPin > TOTAL_PINS) lastPin = TOTAL_PINS;
    for (pin = port * 8; pin < lastPin; pin++) {
      // do not disturb non-digital pins (eg, Rx & Tx)
      if (IS_PIN_DIGITAL(pin)) {
        // only write to OUTPUT and INPUT (enables pullup)
        // do not touch pins in PWM, ANALOG, SERVO or other modes
        if (pinConfig[pin] == OUTPUT || pinConfig[pin] == INPUT) {
          pinWriteMask |= mask;
          pinState[pin] = ((byte)value & mask) ? 1 : 0;
        }
      }
      mask = mask << 1;
    }
    writePort(port, (byte)value, pinWriteMask);
  }
}


// -----------------------------------------------------------------------------
/* sets bits in a bit array (int) to toggle the reporting of the analogIns
 */
//void FirmataClass::setAnalogPinReporting(byte pin, byte state) {
//}
void reportAnalogCallback(byte analogPin, int value)
{
  if (analogPin < TOTAL_ANALOG_PINS) {
    if (value == 0) {
      analogInputsToReport = analogInputsToReport &~ (1 << analogPin);
    } else {
      analogInputsToReport = analogInputsToReport | (1 << analogPin);
    }
  }
  // TODO: save status to EEPROM here, if changed
}

void reportDigitalCallback(byte port, int value)
{
  if (port < TOTAL_PORTS) {
    reportPINs[port] = (byte)value;
  }
  // do not disable analog reporting on these 8 pins, to allow some
  // pins used for digital, others analog.  Instead, allow both types
  // of reporting to be enabled, but check if the pin is configured
  // as analog when sampling the analog inputs.  Likewise, while
  // scanning digital pins, portConfigInputs will mask off values from any
  // pins configured as analog
}

/*==============================================================================
 * SYSEX-BASED commands
 *============================================================================*/

void sysexCallback(byte command, byte argc, byte *argv)
{
  byte mode;
  byte slaveAddress;
  byte slaveRegister;
  byte data;
  unsigned int delayTime;

  switch (command) {
    case I2C_REQUEST:
      mode = argv[1] & I2C_READ_WRITE_MODE_MASK;
      if (argv[1] & I2C_10BIT_ADDRESS_MODE_MASK) {
        Firmata.sendString("10-bit addressing mode is not yet supported");
        return;
      }
      else {
        slaveAddress = argv[0];
      }

      switch (mode) {
        case I2C_WRITE:
          Wire.beginTransmission(slaveAddress);
          for (byte i = 2; i < argc; i += 2) {
            data = argv[i] + (argv[i + 1] << 7);
#if ARDUINO >= 100
            Wire.write(data);
#else
            Wire.send(data);
#endif
          }
          Wire.endTransmission();
          delayMicroseconds(70);
          break;
        case I2C_READ:
          if (argc == 6) {
            // a slave register is specified
            slaveRegister = argv[2] + (argv[3] << 7);
            data = argv[4] + (argv[5] << 7);  // bytes to read
            readAndReportData(slaveAddress, (int)slaveRegister, data);
          }
          else {
            // a slave register is NOT specified
            data = argv[2] + (argv[3] << 7);  // bytes to read
            readAndReportData(slaveAddress, (int)REGISTER_NOT_SPECIFIED, data);
          }
          break;
        case I2C_READ_CONTINUOUSLY:
          if ((queryIndex + 1) >= MAX_QUERIES) {
            // too many queries, just ignore
            Firmata.sendString("too many queries");
            break;
          }
          queryIndex++;
          query[queryIndex].addr = slaveAddress;
          query[queryIndex].reg = argv[2] + (argv[3] << 7);
          query[queryIndex].bytes = argv[4] + (argv[5] << 7);
          break;
        case I2C_STOP_READING:
          byte queryIndexToSkip;
          // if read continuous mode is enabled for only 1 i2c device, disable
          // read continuous reporting for that device
          if (queryIndex <= 0) {
            queryIndex = -1;
          } else {
            // if read continuous mode is enabled for multiple devices,
            // determine which device to stop reading and remove it's data from
            // the array, shifiting other array data to fill the space
            for (byte i = 0; i < queryIndex + 1; i++) {
              if (query[i].addr = slaveAddress) {
                queryIndexToSkip = i;
                break;
              }
            }

            for (byte i = queryIndexToSkip; i < queryIndex + 1; i++) {
              if (i < MAX_QUERIES) {
                query[i].addr = query[i + 1].addr;
                query[i].reg = query[i + 1].addr;
                query[i].bytes = query[i + 1].bytes;
              }
            }
            queryIndex--;
          }
          break;
        default:
          break;
      }
      break;
    case I2C_CONFIG:
      delayTime = (argv[0] + (argv[1] << 7));

      if (delayTime > 0) {
        i2cReadDelayTime = delayTime;
      }

      if (!isI2CEnabled) {
        enableI2CPins();
      }

      break;
    case SERVO_CONFIG:
      if (argc > 4) {
        // these vars are here for clarity, they'll optimized away by the compiler
        byte pin = argv[0];
        int minPulse = argv[1] + (argv[2] << 7);
        int maxPulse = argv[3] + (argv[4] << 7);

        if (IS_PIN_SERVO(pin)) {
          if (servos[PIN_TO_SERVO(pin)].attached())
            servos[PIN_TO_SERVO(pin)].detach();
          servos[PIN_TO_SERVO(pin)].attach(PIN_TO_DIGITAL(pin), minPulse, maxPulse);
          setPinModeCallback(pin, SERVO);
        }
      }
      break;
    case SAMPLING_INTERVAL:
      if (argc > 1) {
        samplingInterval = argv[0] + (argv[1] << 7);
        if (samplingInterval < MINIMUM_SAMPLING_INTERVAL) {
          samplingInterval = MINIMUM_SAMPLING_INTERVAL;
        }
      } else {
        //Firmata.sendString("Not enough data");
      }
      break;
    case EXTENDED_ANALOG:
      if (argc > 1) {
        int val = argv[1];
        if (argc > 2) val |= (argv[2] << 7);
        if (argc > 3) val |= (argv[3] << 14);
        analogWriteCallback(argv[0], val);
      }
      break;
    case CAPABILITY_QUERY:
      Firmata.write(START_SYSEX);
      Firmata.write(CAPABILITY_RESPONSE);
      for (byte pin = 0; pin < TOTAL_PINS; pin++) {
        if (IS_PIN_DIGITAL(pin)) {
          Firmata.write((byte)INPUT);
          Firmata.write(1);
          Firmata.write((byte)OUTPUT);
          Firmata.write(1);
        }
        if (IS_PIN_ANALOG(pin)) {
          Firmata.write(ANALOG);
          Firmata.write(10);
        }
        if (IS_PIN_PWM(pin)) {
          Firmata.write(PWM);
          Firmata.write(8);
        }
        if (IS_PIN_SERVO(pin)) {
          Firmata.write(SERVO);
          Firmata.write(14);
        }
        if (IS_PIN_I2C(pin)) {
          Firmata.write(I2C);
          Firmata.write(1);  // to do: determine appropriate value
        }
        Firmata.write(127);
      }
      Firmata.write(END_SYSEX);
      break;
    case PIN_STATE_QUERY:
      if (argc > 0) {
        byte pin = argv[0];
        Firmata.write(START_SYSEX);
        Firmata.write(PIN_STATE_RESPONSE);
        Firmata.write(pin);
        if (pin < TOTAL_PINS) {
          Firmata.write((byte)pinConfig[pin]);
          Firmata.write((byte)pinState[pin] & 0x7F);
          if (pinState[pin] & 0xFF80) Firmata.write((byte)(pinState[pin] >> 7) & 0x7F);
          if (pinState[pin] & 0xC000) Firmata.write((byte)(pinState[pin] >> 14) & 0x7F);
        }
        Firmata.write(END_SYSEX);
      }
      break;
    case ANALOG_MAPPING_QUERY:
      Firmata.write(START_SYSEX);
      Firmata.write(ANALOG_MAPPING_RESPONSE);
      for (byte pin = 0; pin < TOTAL_PINS; pin++) {
        Firmata.write(IS_PIN_ANALOG(pin) ? PIN_TO_ANALOG(pin) : 127);
      }
      Firmata.write(END_SYSEX);
      break;
      
    //************* Custom Commands ************//
    //******************************************//
    case 0x08:
    { //tone function
      //Arg 0 = Port
      //Arg 1...argc = Frequency
      //Determine frequency from text
      int placeCounter = 1;
      int freq = 0;
      for (int i = argc - 1; i > 0; i--){
        freq += (argv[i] - 48) * placeCounter;
        placeCounter *= 10;
      }

      tone(argv[0], freq);
      break;
    }
  
    case 0x09: //noTone function
      noTone(argv[0]);
      break;

    case 0x0A: // RGB color/brightness change
      colorWipe(RGB_LED.Color(argv[0], argv[1], argv[2]), 50); // Initialize all pixels to 'off'
      RGB_LED.setBrightness(argv[3]);
      break;
    case 0x0B:
      GetRange();
      break;
    case 0x0C:
        switch(argv[0]) {
         case 0x00: Matrix.SlideLeft(argv[1]); break;
         case 0x01: Matrix.SlideRight(argv[1]); break;
         case 0x02: Matrix.ChangeBrightness(argv[1]); break;
         case 0x03: Matrix.DisplayText((unsigned char*) &argv[1], 0); showMatrix = 1; break;
         case 0x04: Matrix.clear(); Matrix.UpdateMatrix(); showMatrix=0; break;
         default: break;
                
     }
       
  }
}

void enableI2CPins()
{
  byte i;
  // is there a faster way to do this? would probaby require importing
  // Arduino.h to get SCL and SDA pins
  for (i = 0; i < TOTAL_PINS; i++) {
    if (IS_PIN_I2C(i)) {
      // mark pins as i2c so they are ignore in non i2c data requests
      setPinModeCallback(i, I2C);
    }
  }

  isI2CEnabled = true;

  // is there enough time before the first I2C request to call this here?
  Wire.begin();
}

/* disable the i2c pins so they can be used for other functions */
void disableI2CPins() {
  isI2CEnabled = false;
  // disable read continuous mode for all devices
  queryIndex = -1;
  // uncomment the following if or when the end() method is added to Wire library
  // Wire.end();
}

/*==============================================================================
 * SETUP()
 *============================================================================*/
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
void loop()
{
  byte pin, analogPin;
  if(showMatrix)
   Matrix.UpdateText ();
  /* DIGITALREAD - as fast as possible, check for changes and output them to the
   * FTDI buffer using Serial.print()  */
  checkDigitalInputs();

  /* SERIALREAD - processing incoming messagse as soon as possible, while still
   * checking digital inputs.  */
  while (Firmata.available())
    Firmata.processInput();

  /* SEND FTDI WRITE BUFFER - make sure that the FTDI buffer doesn't go over
   * 60 bytes. use a timer to sending an event character every 4 ms to
   * trigger the buffer to dump. */

  currentMillis = millis();
  if (currentMillis - previousMillis > samplingInterval) {
    previousMillis += samplingInterval;
    /* ANALOGREAD - do all analogReads() at the configured sampling interval */
    for (pin = 0; pin < TOTAL_PINS; pin++) {
      if (IS_PIN_ANALOG(pin) && pinConfig[pin] == ANALOG) {
        analogPin = PIN_TO_ANALOG(pin);
        if (analogInputsToReport & (1 << analogPin)) {
          Firmata.sendAnalog(analogPin, analogRead(analogPin));
        }
      }
    }
    // report i2c data for all device with read continuous mode enabled
    if (queryIndex > -1) {
      for (byte i = 0; i < queryIndex + 1; i++) {
        readAndReportData(query[i].addr, query[i].reg, query[i].bytes);
      }
    }
  }
}

void colorWipe(uint32_t c, uint8_t wait) {
  for(uint16_t i=0; i<RGB_LED.numPixels(); i++) {
      RGB_LED.setPixelColor(i, c);
      RGB_LED.show();
      delay(wait);
  }
}

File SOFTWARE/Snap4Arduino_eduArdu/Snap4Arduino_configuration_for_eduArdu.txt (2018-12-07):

How to configure Snap4Arduino for eduArdu:

1. Download and install Snap4Arduino from: http://snap4arduino.rocks/

2. Download and install latest Arduino IDE,
   run it and Include the libraries from ./libraries directory in ARDUINO IDE:
   Sketch->Include Library-> Add .ZIP library

3. Open "eduArdu_Firmata.ino" located in ./eduArdu_Firmata

4. Select a board to be Olimex32-u4 or Arduino Leonardo, select com port, get board info

5. Upload the sketch

6. Launch Snap4Arduino

7. From the File menu choose "Import" and select eduArdu.xml file located in this directory

8. Click on the Arduino label, located on the main screen of Snap4Arduino

9. Now you can see additional eduArdu blocks

10. Press " Connect Arduino " button located on the left pane

11. You will see dialog box confirming that you have been connected to Arduino (eduArdu)

12. Now you can create interractive Snap programs.

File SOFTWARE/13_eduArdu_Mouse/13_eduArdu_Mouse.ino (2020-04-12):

/**********************************************************************
Demo example for Olimex board eduArdu
Tested with Arduino 1.8.8
Date: 2018/12/12

Description:
Demo sketch using the default Arduino library "Mouse" based on their
example JoystickMouseControl. Using the joystick you move the cursor
and when you press the button you trigger left click.
**********************************************************************/

#include "Mouse.h"
#include <Olimex_Joystick.h>

// set pin numbers for switch, joystick axes, and LED:
const int switchPin = 2;      // switch to turn on and off mouse control
const int ledPin = 5;         // Mouse control LED
Olimex_Joystick Joy (A0, A1);

// parameters for reading the joystick:
int range = 12;               // output range of X or Y movement
int responseDelay = 5;        // response delay of the mouse, in ms
int threshold = range / 4;    // resting threshold
int center = range / 2;       // resting position value

boolean mouseIsActive = false;    // whether or not to control the mouse
int lastSwitchState = LOW;        // previous switch state

void setup() {
  pinMode(switchPin, INPUT);       // the switch pin
  pinMode(ledPin, OUTPUT);         // the LED pin
  // take control of the mouse:
  Mouse.begin();
}

void loop() {
  // read the switch:
  int switchState = digitalRead(switchPin);
  // if it's changed and it's high, toggle the mouse state:
  if (switchState != lastSwitchState) {
    if (switchState == HIGH) {
      mouseIsActive = !mouseIsActive;
      // turn on LED to indicate mouse state:
      digitalWrite(ledPin, mouseIsActive);
    }
  }
  // save switch state for next comparison:
  lastSwitchState = switchState;

  // read and scale the two axes:
  int xReading = readAxis(A0);
  int yReading = readAxis(A1);
  Serial.println (xReading);
  Serial.println (yReading);

  // if the mouse control state is active, move the mouse:
  if (mouseIsActive) {
    Mouse.move(xReading, yReading, 0);
  }

  // read the mouse button and click or not click:
  // if the mouse button is pressed:
  if (Joy.But()) {
    // if the mouse is not pressed, press it:
    if (!Mouse.isPressed(MOUSE_LEFT)) {
      Mouse.press(MOUSE_LEFT);
    }
  }
  // else the mouse button is not pressed:
  else {
    // if the mouse is pressed, release it:
    if (Mouse.isPressed(MOUSE_LEFT)) {
      Mouse.release(MOUSE_LEFT);
    }
  }

  delay(responseDelay);
}

/*
  reads an axis (0 or 1 for x or y) and scales the analog input range to a range
  from 0 to <range>
*/

int readAxis(int thisAxis)
{
  // read the analog input:
  int reading;
  if (thisAxis == A1)
    reading = 1023 - analogRead(thisAxis);
  else
    reading = analogRead(thisAxis);

  // map the reading from the analog input range to the output range:
  reading = map(reading, 0, 1023, 0, range);

  // if the output reading is outside from the rest position threshold, use it:
  int distance = reading - center;

  if (abs(distance) < threshold) {
    distance = 0;
  }

  // return the distance for this axis:
  return distance;
}

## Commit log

2018-12-07 Initial upload of PCB CAD files, Arduino examples and how to configure Snap4Arduino to work with eduArdu
    [10118194.step, ALSRobot-BUZZER.step, JS-PS2.step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]
2018-12-10 label D13 changed to D23
    [eduArdu_Rev_B.kicad_pcb]
2018-12-17 fix firmata size
    [Snap4Arduino_configuration_for_eduArdu.txt]
2018-12-23 README.md: Add getting started notes
    Add the exact steps to get stareted with the provided examples
    in Arduino IDE by importing the libraries, compiling and
    uploading the sketches to Olimex eduArdu.
2019-04-04 15_eduArdu_IR_LED.ino: Change LED on IR signal
    The code controls the LED changing its color depending on the infrared signal sent to it.
    Tested with Samsung remote controller. Currently supports 2 colours corresponding to two IR signals.
2019-07-16 Capacitive Buttons, Robot, LED Matrix, Arduino install
2020-04-08 updated libraries add 21 22 demo code, upload challenges
    [Snap4Arduino_configuration_for_eduArdu.txt]
2020-04-12 modemmanager fix reported by Leon Anavi
    [Snap4Arduino_configuration_for_eduArdu.txt]

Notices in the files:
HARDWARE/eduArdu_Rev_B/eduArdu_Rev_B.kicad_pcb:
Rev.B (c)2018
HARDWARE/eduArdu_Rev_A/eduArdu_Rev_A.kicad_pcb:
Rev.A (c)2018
